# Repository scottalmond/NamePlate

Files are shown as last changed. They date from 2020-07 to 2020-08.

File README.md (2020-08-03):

# Name Plate Overview

Many cubicles are adorned with a standard aluminum name plate holding a piece of paper denoting the occupant's name.  This project presents an upgraded name tag that is backlit with LEDs.

This project was started as something simple to get active again after the COVID-19 lockdown.  Intent was to produce a visually engaging product with a price point at or below $25 in small production runs (10 units) to be in compliance with corporate gifting guidelines.

This unit employs nominally 100 WS2812B "NeoPixel" RGBW LEDs.  An ATtiny3216 was selected as a well supported processor (Arduino IDE) with a sizable flash memory (32kB).  To keep the design margin large, the SOIC package was selected.

The user can adjust the brightness of the unit through a potentiometer.  A Periphreal Touch Controller button allows quick user input while a hall effect sensor allows administrative functions.  A DIP switch allows for operation mode selection

# Assembled Unit

# Constituent Components

## Bill of Materials

## PCB

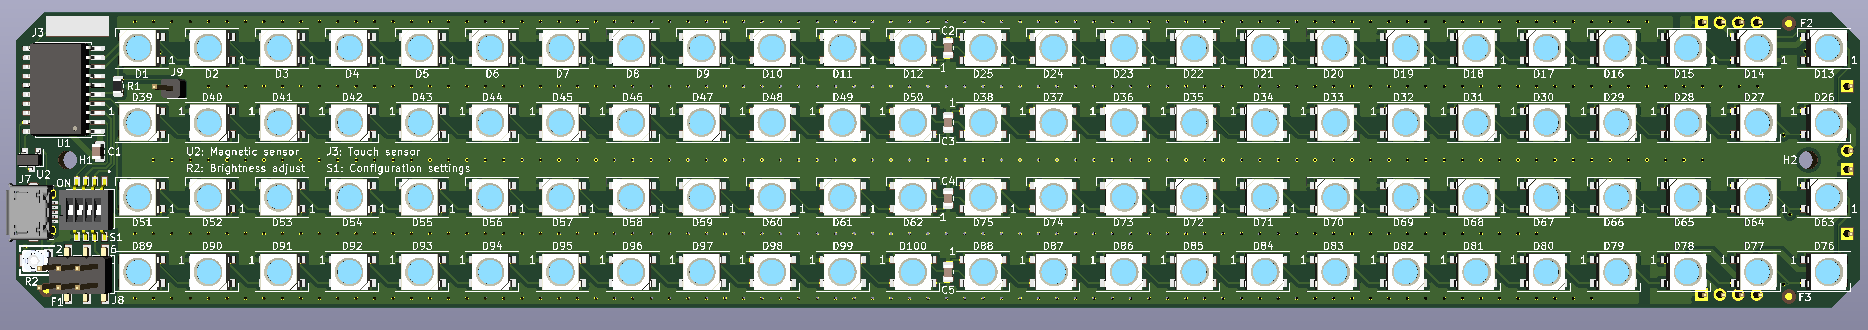
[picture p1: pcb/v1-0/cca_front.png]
CCA Front

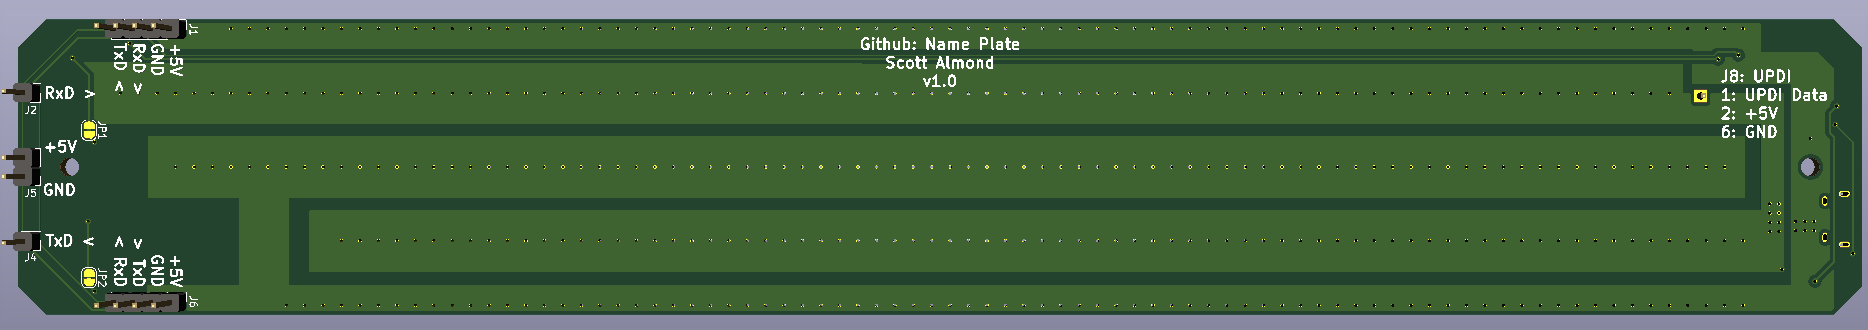
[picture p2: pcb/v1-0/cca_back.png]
CCA Back


## Case

## Display Mask

## Face Plate

## Programmer

Direct referenced from: http://www.technoblogy.com/show?2OCH

- Install ElTangas's jtag2updi on Arduino Uno, Duemilanova or equivalent ATmega328p.  -- Details for making UPDI programmer: https://github.com/SpenceKonde/megaTinyCore/blob/master/MakeUPDIProgrammer.md
-- Use pin PD6 for UPDI I/O
- Install Spence Konde's megaTinyCore in the Arduino IDE
-- Instructions: https://github.com/SpenceKonde/megaTinyCore/blob/master/Installation.md
-- add to additional board URLs: http://drazzy.com/package_drazzy.com_index.json
-- boards manager add: "megaTinyCore" v2.0.5
- Upload settings:
-- Processor: ATtiny3216
-- 4.2 V BOD
-- 16 MHz
-- Programmer: jtag2updi

J8:
Pin 1: UPDI
Pin 2: +5V
Pin 6: GND

## Processor

doc: http://ww1.microchip.com/downloads/en/DeviceDoc/ATtiny3216-17-DataSheet-DS40002205A.pdf

# Periphreals

## DC Power

Note that this unit can sink substancial current.  It is recommended to power the unit with a 5V USB adapter capable of sourcing 2 Amps or more.

## LEDs [PA7]

## Touch Button [PB0]

Touching and releasing the very upper-left corner of the device for nominally 0.5 seconds will register a tap.  The unit will transition  between display patterns.

## Hall effect sensor [PA3]

Place a fridge or hard drive magnet just above the USB port.  This will activate <TBD function - implemented as fallback if PTC was problematic>

## Brightness Potentiometer [PA2]

Uncover the circuit board by removing the two thumb screws on either side of the faceplate.  Rotate the Philips potentiometer at the bottom left of the unit CW (?) to increase brightness.

## DIP Switch Settings [PA6, PA5, PA4]

Position 1:
Set to "OFF" to allow the displayed pattern to automaically update daily.  Set to "ON" to hold the currrently displayed pattern indefinitely.

Position 2:
Set to "ON" to configure the unit for collaboration mode.  In this mode the unit will communicate with other circuit boards to coordinate the displayed pattern.  For single PCB operation, the normal operation mode is "OFF".

Position 3:
Set to "ON" to enable diagnostic mode to allow verification and troublshooting of the user interfaces and outputs.  "OFF" is normal device operation.

Position 4:
Set to "ON" to connect the ID pin of the microUSB port to to the UPDI pin on the micro controller.  This is used for programming of the device without removing the circuit board from the casing.  "OFF" is normal operation.

# Collaboration Mode [PxD: PB2, RxD: PB3]

Multiple PCBs can be linked together to produce a larger display.  
<TBR>

# TODO

Add area for writing in owner name on PCB, for tracking units through development (if code differs)
Add CC BY 4.0 license to schematic
add year produced to PCB
>>> allow for batteyr power and power switch
>>> consider accel and swinging unit to create persistence of vision text display
add schematic links to readme.md
get solder paste with thinner tip
*** move micro USB header - difficult to reach for rework with config switches behind it (layout design issue)
note: LED is N/C in layout - why not flagged in DRc...?
b/c omitted connection in schematic due to copy-paste omission...
***fix D60 connection to 5V in next rev (schematic DRC issue)
-- run DRC in schematic too...
note: screw reads ~4V on delivery
magnet stuck at 0.87V despite exposure to hard drive magnet...
tried with pullup, still rigid at 0.87V
part is hot to the touch
note, the schematic part is AH1806 (hall switch) which has different pinout
- used this footprint because no footprint was supplied by vendor
*** next rev to swap pins 2 and 3 (schematic footprint issue)
consider testability point for EVERY IO
in user guide, include diagrams of expected UI screen output, ref 11.7V battery charger manual
include build number in start up script
compare findings on this CCA vs pendant which had button rotate 90 degrees (schematic footprint issue) and traces too close to holes (layout issue)
consider swapping hall effect sensor and brightness - allow greater accessibility to magnetic input
note:0.37" from LED-surface to top of programming header [note: 0.38" per data sheet, erxcluding solder]
contiguous undervolt - dim screen brighntess (LiPo response to dropping voltage)
min stackup (NO 1/16" acry): pcb 1.6 mm/0.063", 100 mil UPDI: 0.37", 0.125" acrylic face, 0.05" margin: 0.608"
max stackup (NO 1/16" acry): [5 turns 4-40 is 0.1250"] [50 mil backing], 200 mil standoff, 0.608" from above: 0.808"
min w/ 1/16 acry: 0.63+ above = 0.671"
max w/ 1/16 acry: 0.63+ above = 0.871"
note: thumb screw head 11/64" thick BEYOND base length above
0.75" is max length fully threaded.  next step up is 1"
note: head diameter on thumb screw is 5/16"
.75-1/8"+.05 back = 
box height at 0.8".  Add 1/16" when fabricating with acrylic
>>> enlarge PCB holes to be close fit.  Currently too small
allow for flipping vertically - flip flag, matrix rtain, etc
>>> consider moving silk screen contact info to behind a hole in the back of the unit
v1-0 --> v1-1 case:
50 mil WAS --> 100 mil IS margin inside pcb-to-case
50 mil WAS --> 150 mil IS wall thickness
WAS circle vent holes --> IS diamond vent holes --> will turn off supports
WAS 4x PCB holders, IS 2x PCB holders in the center
WAS NO chamfer inside unit --> IS chamfer around inner edge to provide wall support
WAS 4x faceplate holders --> IS NO facaeplate holders
WAS NO USB port --> IS USB PORT --> need dimensions of usb plug, and concern with unsupported 3d print
micro usb header metal = 0.07", 0.2" from opposing side of usb to verrtical case edge, 0.31" total
0.27" wide, 0.35" from opposing edge to case, 0.43" total
kicad center hole at 3.8" Y, 4.083" for microUSB port center
microUSB center 1.2 mm above surface of PCB
consider first boot (all 1's in EEPROM) to debug chaper.  First user input to change EEPROM exits hidden chapter
*** consider screw slots due to 3d print contraction
current draw?
leakage through usb port?
*** add lip to top edge to hide cut paper
consider standoffs (3d print?)
wasn't thinking about plastic contraction between ~10" separated holes
didn't think about light leakage through walls of solid plastic
note: the link from this pcb to others on the top/bottom has led pads very clodse to the power/ground rails
note: grips to hold pcb in place are non-effective (pcb too thin?)
consider pcb design features that allow for 2x rows of LEDs, NOT 4
didn't realize how short the final letts would be
debug screen: voltage, build #
1.8A at full brightness in full-screen mode (green colors)

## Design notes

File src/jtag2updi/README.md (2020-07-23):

# jtag2updi

This fork of the repo has been stripped down and modified so that folders don't need to be renamed in order to compile with the Arduino IDE. 
## New Features
This has also has the following additions:
* Support for DA-series and upcoming DB-series parts; correct mode for reading and writing is deduced by reading the SIB
* Timeout function - a lack of messages from host for 250ms or the target failing to send an expected response for 100ms will result in a timeout. Timeouts from target are reported to host. Timeouts waiting for host will lead to it attempting to reset a failed status message (on the grounds that "maybe it didn't get through". Four consecutive timeouts waiting for host will cause it to reset to it's initial state and await a new attempt at communication from the host. 
* Improve write speed by disabling the response signature during burst writes (NO_ACK_WRITE).
* Add debug channel via SPI or second USART to provide rich debugging output.
* Add support for running on addittional processors: 40/44 pin ATmega parts (ones supported by MightyCore), 64/100-pin ATmega parts (ones supported by MegaCore), 28/32-pin ATmega parts (ones supported by MiniCore), and megaAVR 0-series parts (supported by MegaCoreX). The tinyAVR 0-series and 1-series parts (supported by megaTinyCore) are also supported.

## Known issues
There are the following known issues:
* Timeout system breaks compatibility with terminal mode (-t option), by definition, as a user in terminal mode will inevitably take longer than it is configured to wait. This will be corrected via a planned SUPPORT_TERMINAL_MODE option for those small number of users who use terminal mode.
* Does not work correctly on LGT-based clones
* has_pdi does not work correctly (waiting to hear back whether it is broken for all parts or just DA-series parts)
* Does not run on DA-series parts - This will be corrected by addition of a few more defines, should be easy
* Does not support targets operating at a low voltage - this could be solved by using an analog comparator for receiving, and using pin in "open drain" mode for transmitting, but I doubt I'll ever bother to implement this.

# Original Readme
This is a firmware, that when uploaded on an atmega328p, or a similar AVR MCU, enables it to interface with avrdude using the jtagice Mk2 protocol via a serial link. In particular, you can use an Arduino to host this firmware.
It provides a bridge to program the new attiny817 family of MCUs, that use the UPDI interface:

avrdude -> HW Serial interface -> Programmer MCU (e.g. Mega328P) -> SW Serial on PD6 -> Target MCU (e.g. tiny817)

Currently, I have not tested this software with a level shifter, however, since the UPDI pin is high voltage tolerant, it's ok to have V_prog > V_target, but not the reverse.

Notice, however, that the logic levels need to be compatible for successful programming: V_target cannot be lower than about 60% of V_prog (60% will likelly work, 70% is guaranteed to work). Therefore, it will not be possible to program a 2.5V target with a 5.0V programmer, because communication errors will surely occur (but no electrical damage), but if V_target is 3.3V (66% of 5.0V) chances are good.

<pre>
                                            V_prog                 V_target
                                              +-+                     +-+
                                               |                       |
 +----------+          +---------------------+ |                       | +--------------------+
 | PC       |          | Programmer          +-+                       +-+  Target            |
 | avrdude  |          |                     |      +----------+         |                    |
 |       TX +----------+ RX              PD6 +------+   4k7    +---------+ UPDI               |
 |          |          |                     |      +----------+         |                    |
 |       RX +----------+ TX                  |                           |                    |
 |          |          |                     |                           |                    |
 |          |          |                     |                           |                    |
 |          |          |                     +--+                     +--+                    |
 +----------+          +---------------------+  |                     |  +--------------------+
             JTAGICE MkII                      +-+     UPDI          +-+
             Protocol                          GND     Protocol      GND

</pre>
Drawing adapted from: https://github.com/mraardvark/pyupdi

If you use an Arduino as host for this program, be sure that, after burning the software, you disable its auto-reset feature, using one of the techniques described here:
https://playground.arduino.cc/Main/DisablingAutoResetOnSerialConnection

Alternatively, you can use an Arduino without integrated USB/serial adapter, like the pro-mini; in that case, just disconecting the DTR wire will disable the auto-reset. Just remember the UPDI chip must be connected to the same supply voltage as the Arduino's MCU!

## Building with Arduino IDE

The program can be built as if it was an Arduino sketch. 

Open jtag2updi.ino in the jtag2updi folder, and upload to your microcontroller. 

The Arduino IDE will automatically set the correct MCU model and F_CPU, but if you want to change the speed of the UPDI link, you will have to edit UPDI_BAUD directly in the source code.

## Using with avrdude

**If using megaTinyCore, you can ignore all this stuff**

You will find a modified avrdude.conf file in the base folder. This is based on the current avrdude.conf file from:
http://svn.savannah.gnu.org/viewvc/*checkout*/avrdude/trunk/avrdude/avrdude.conf.in?revision=1422

It has been modified to work with avrdude 6.3, by removing (actually, commenting out) some incompatible stuff, and adding the "jtag2updi" programmer type.

The definitions for UPDI chips were slightly modified so that avrdude thinks they use the PDI programming interface instead of UPDI (i.e., avrdude thinks they are some kind of XMegas).

This allows the jtagice mk2 protocol to be used for programming UPDI chips, since this protocol predates UPDI and is not formally compatible with it. Originally, I had planed to use the STK500v2 protocol, and emulate the ISP interface, and I actually wrote an ISP version of the programmer software.

However, this would require entirely new definitions for the UPDI chips inside the avrdude.conf file, while using jtagice2 requires only very slight changes to the definions provided by Atmel (now Microchip).

Jtagice mk2 is the most advanced of Atmel's programming protocols that still supports a UART serial connection instead of USB, making it easily compatible with any Arduino you choose to host this software, and any OS you run avrdude on.

It's major limitation is speed; it can't go over 115200 Baud, because the protocol lacks definitions for higher speeds. It's actually inferior to the STK500v2 protocol in this respect, this older standard can run at any speed avrdude instructs it to.

Fortunately, the current UPDI chips do not have very large flash memories, so I think this isn't a major issue.

<b>Example command line (windows):</b>
<pre>
avrdude -c jtag2updi -P com7 -p t1614
</pre>

If all the connections are correct and the target is indeed an *unlocked* tiny1614, the output will be:
<pre>
avrdude: AVR device initialized and ready to accept instructions

Reading | ################################################## | 100% 0.03s

avrdude: Device signature = 0x1e9422 (probably t1614)

avrdude done.  Thank you.
</pre>

If the chip is locked, the output will be:
<pre>
avrdude: jtagmkII_reset(): bad response to reset command: RSP_ILLEGAL_MCU_STATE
avrdude: initialization failed, rc=-1
         Double check connections and try again, or use -F to override
         this check.

avrdude: jtagmkII_close(): bad response to sign-off command: RSP_ILLEGAL_MCU_STATE

avrdude done.  Thank you.
</pre>

To unlock the chip, you need to erase it. Currently, the "-e" option is not working with jtag2updi, let's call it a known bug, so you need to enter interactive mode, using "-t", and "-F" to override the error:
<pre>
avrdude -c jtag2updi -P com7 -p t1614 -U flash -t -F
</pre>

You will enter the avrdude prompt:
<pre>
avrdude: jtagmkII_reset(): bad response to reset command: RSP_ILLEGAL_MCU_STATE
avrdude: initialization failed, rc=-1
avrdude: AVR device initialized and ready to accept instructions
avrdude: Device signature = 0xffff00
avrdude: Expected signature for ATtiny1614 is 1E 94 22
avrdude: NOTE: Programmer supports page erase for Xmega devices.
         Each page will be erased before programming it, but no chip erase is performed.
         To disable page erases, specify the -D option; for a chip-erase, use the -e option.
avrdude>
</pre>

Enter "erase" then "quit" and the chip will be unlocked (and erased).
<pre>
avrdude> erase
>>> erase
avrdude: erasing chip
avrdude> quit
>>> quit

avrdude done.  Thank you.
</pre>

## Troubleshooting

If you have triple-checked all the connections but still getting errors, the problem might be the speed of the serial links. I have set the jtag2updi entry on the avrdude configuration file to run at 115200 baud by default. This baud rate can cause errors, for example, if your MCU is running at 8MHz.

This can be changed with the avrdude "-b" option. Valid baud rates are 2400, 4800, 9600, 14400, 19200, 38400, 57600 and 115200. You can make the setting permanent by editing the jtag2updi entry on "avrdude.conf".

If the trouble is on the UPDI link, a slower speed can be selected by changing UPDI_BAUD and recompiling.

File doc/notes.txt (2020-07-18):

1,3
11,4.6

1.25,3.25
10.75,4.35

1.262,3.262
10.738,4.338

1.012,3.012
10.988,4.588

11 - .2 -.015

24 10.785
0 

10.818 + .012
10.83

0.17" edge
3.182

4.6-.17-.012
11-.17-.012

.14 

24 10.785
0 1.65

*24 10.804
delta 0.38
*0 1.684

1.684+C*0.38
3.2, 3.6, 4.0, 4.4 --> 0.403
3.1955,3.5985,4.0015,4.4045
rows 0 and 2 rotated 180

0.38 per LED hori

-- case

PCB: 1.6 x 10"
outline +- 0.15 mm --> 0.006"

1.6+.006+.006 = 1.612
round up to 50 mil
1.65 inner
1.7 outer

same horizontally
10.05 inner
10.1 outer

.15 cut on PCB

10.72 hole
1.28 hole
9.44" apart

40 threads per inch on 4-40
5 threads engaged minimum
0.125" plastic

also allow 50 mil error on height

4-40 hole size
https://learn.sparkfun.com/tutorials/getting-started-with-3d-printing-using-tinkercad/taking-measurements

consider heat set inserts for repeated insertion/extraction of thumb screws

screw into cubicle wall with something on the order of #2 gauge 1/4"?
https://titleplates.com/resources/attaching-nameplates.html

consider for how to get cabling out of rear

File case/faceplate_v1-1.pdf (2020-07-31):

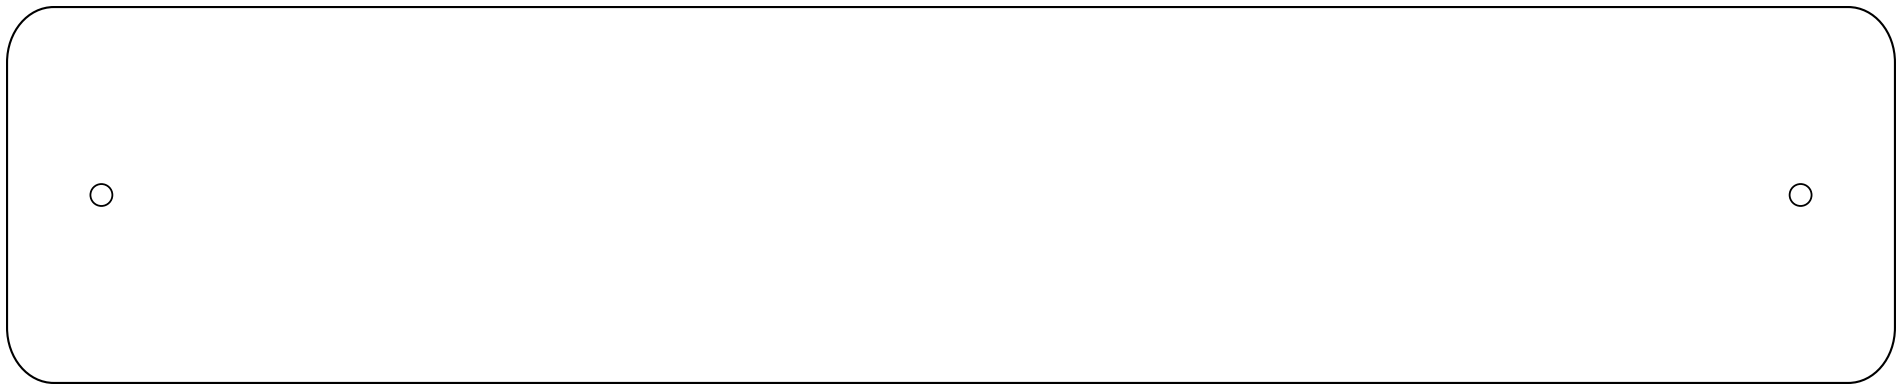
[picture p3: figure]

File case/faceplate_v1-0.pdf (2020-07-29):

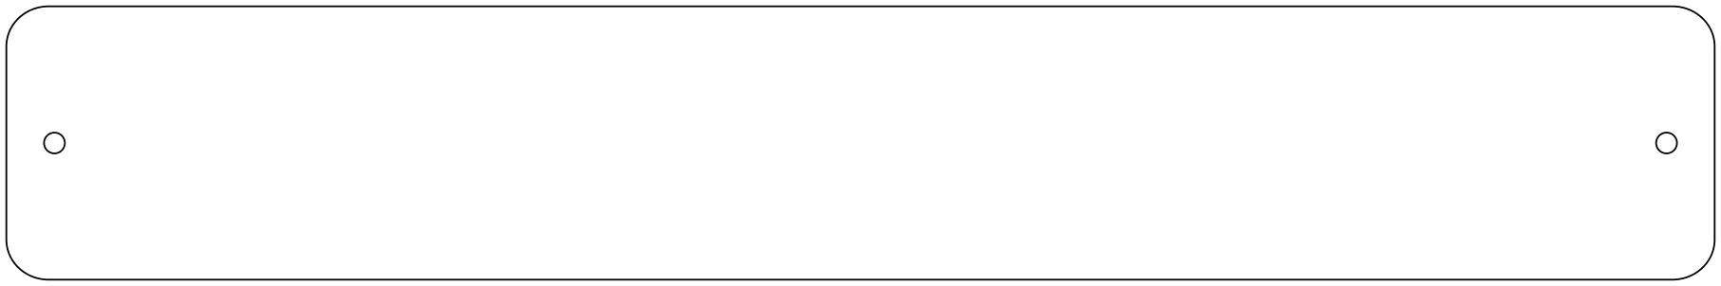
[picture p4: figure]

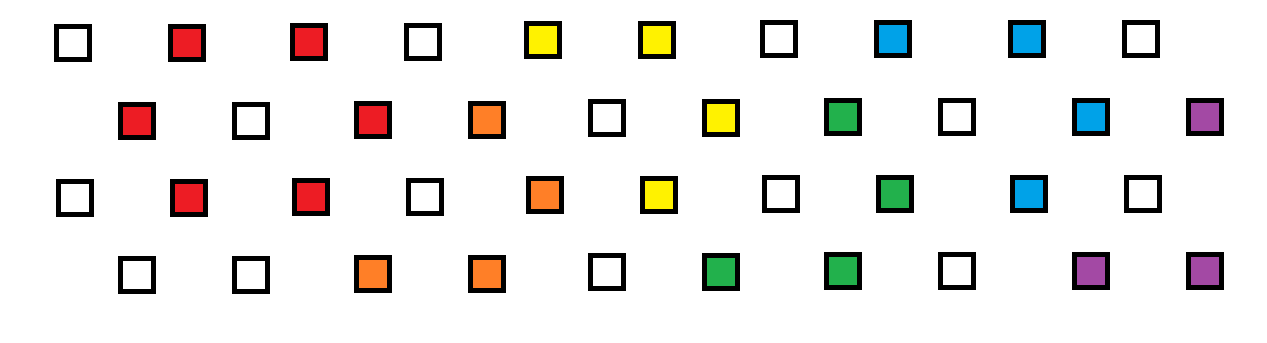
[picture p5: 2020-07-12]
doc/circle_loops_animation_concept.png

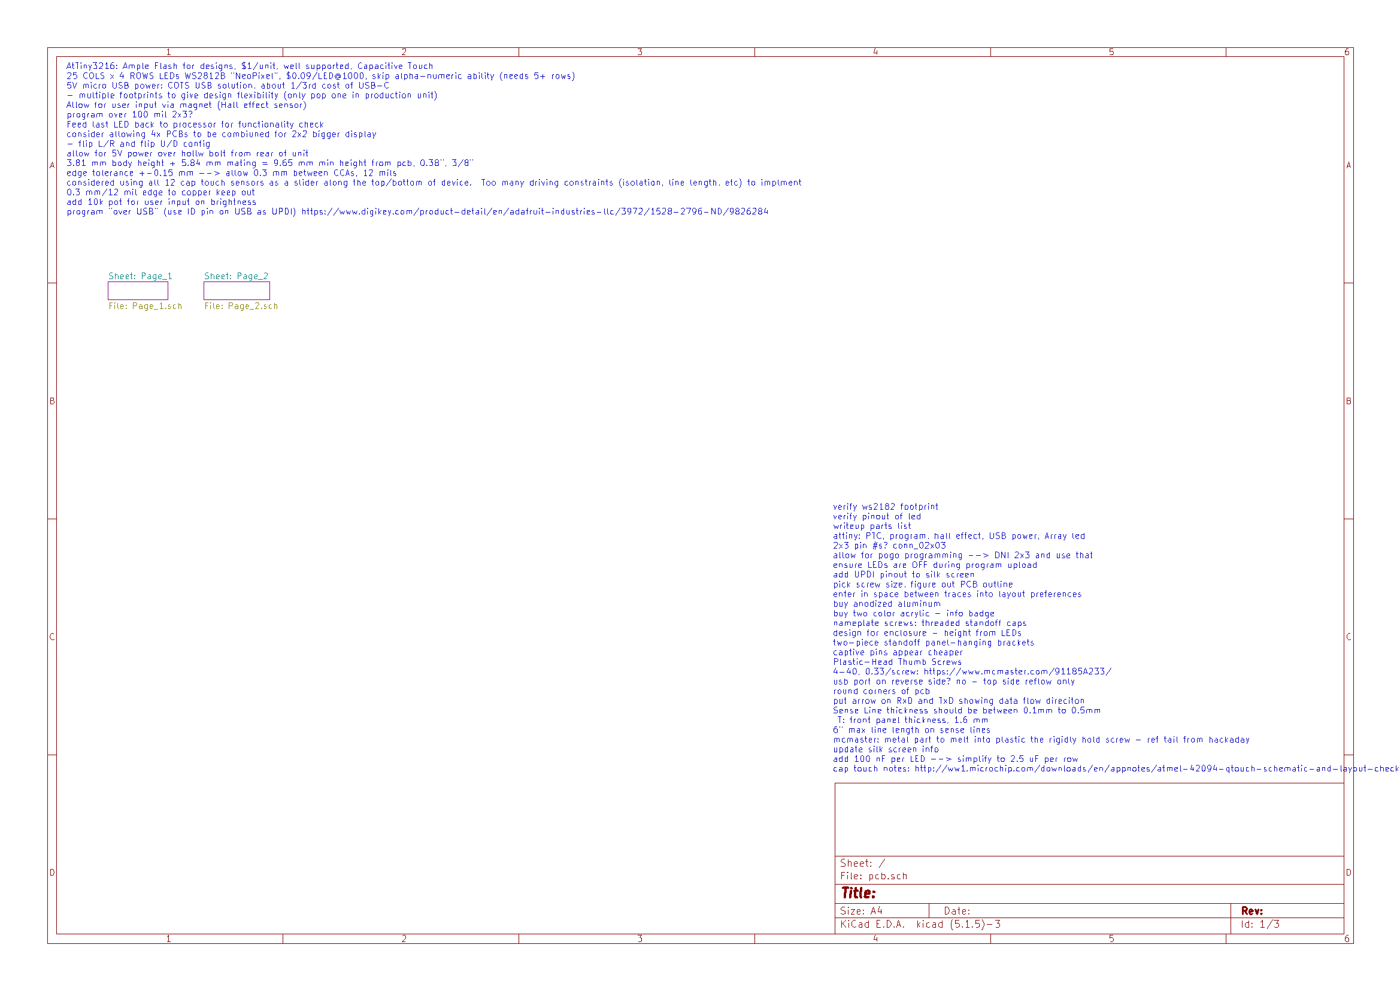
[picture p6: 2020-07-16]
pcb/v1-0/schematic_notes.png

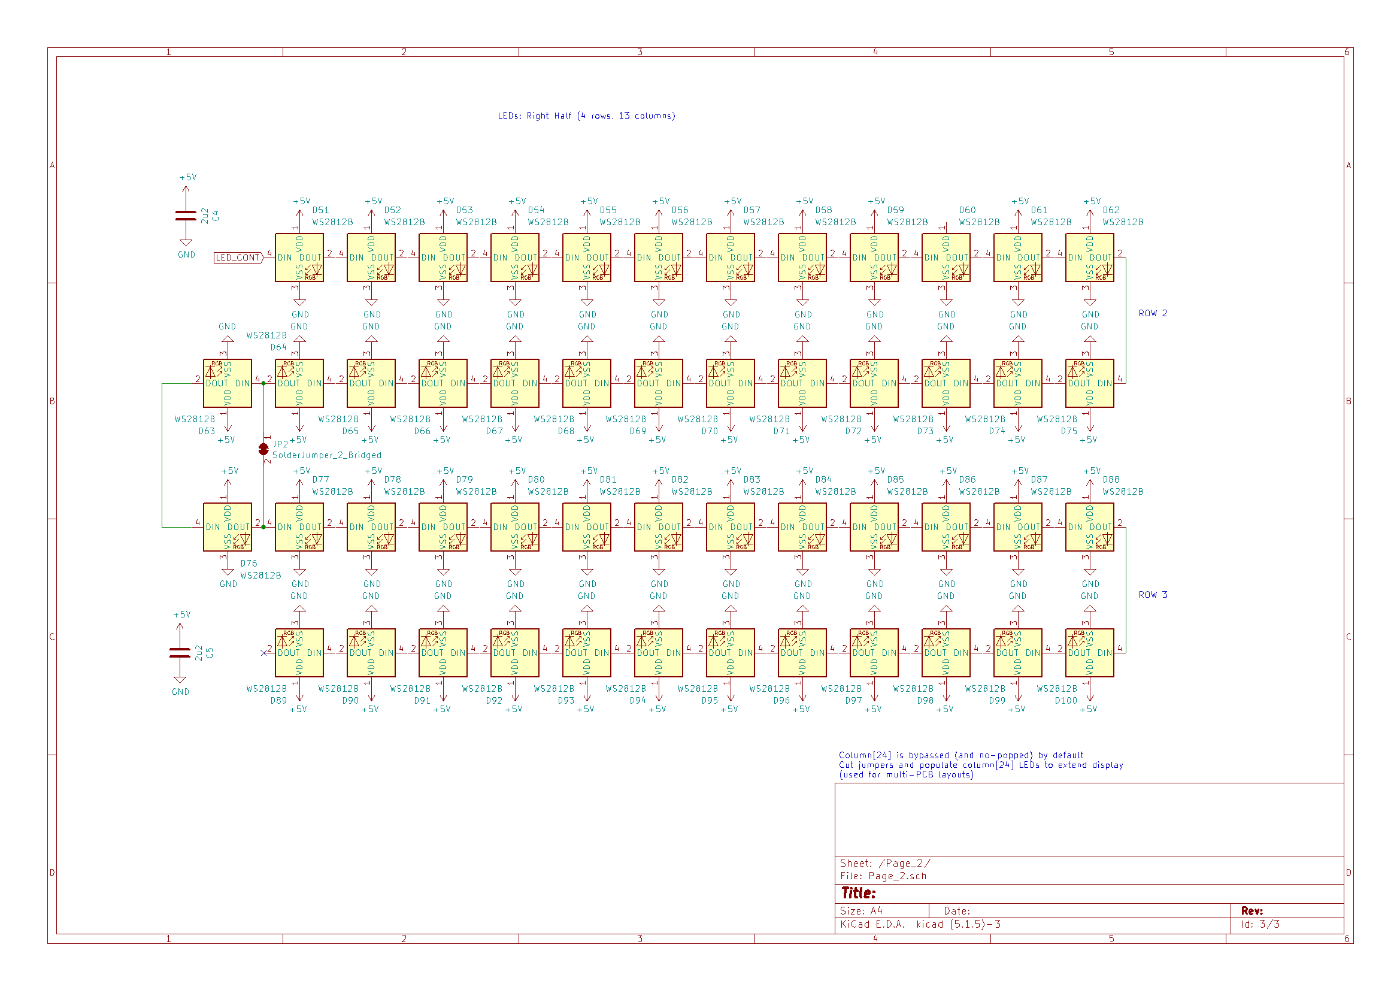
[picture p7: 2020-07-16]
pcb/v1-0/schematic_page2.png

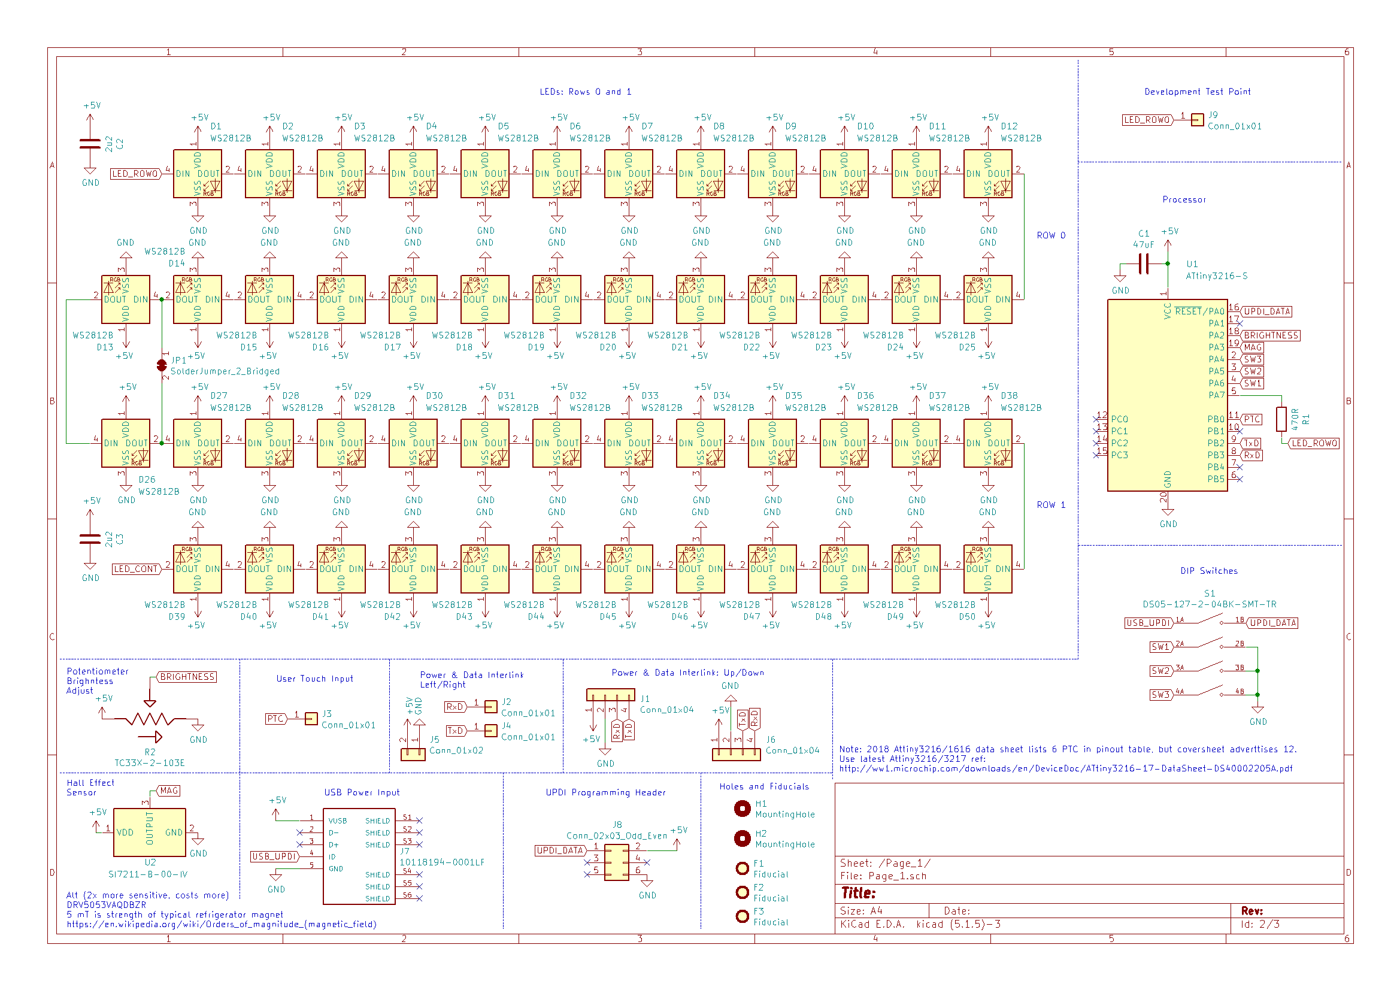
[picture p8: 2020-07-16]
pcb/v1-0/schematic_page1.png

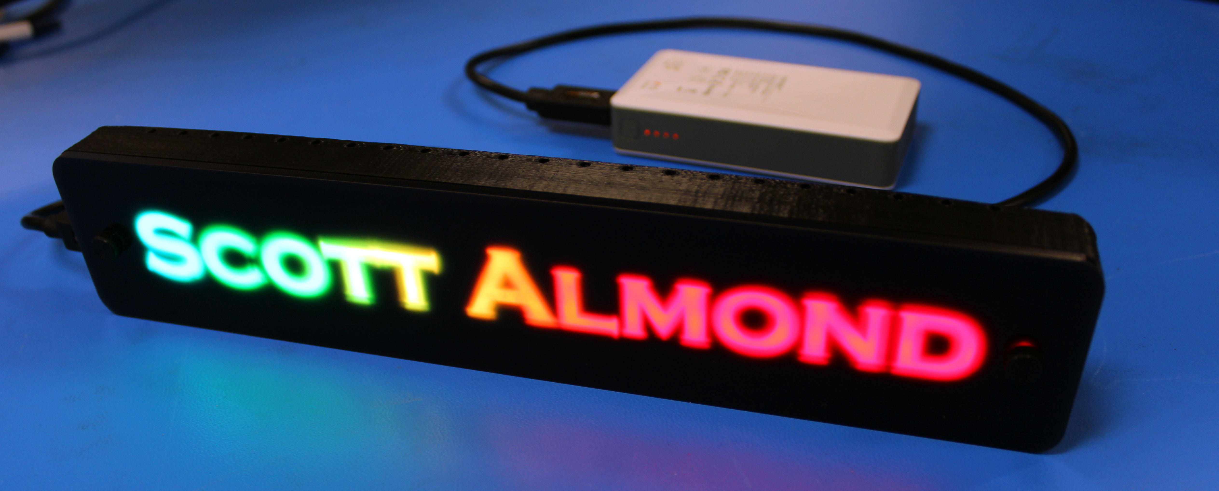
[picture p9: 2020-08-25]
doc/img/IMG_5587_cropped.JPG

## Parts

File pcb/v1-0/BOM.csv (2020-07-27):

Footprint | Part Number | Value | Description | Qty/assembly | Unit Price (@10 assemblies) | Extended Price per Unit | Link
C1 | CC0805MKX5R5BB476 | 47 uF | 0805 Capacitor, >5V | 1 | 0.341 | 0.341 | https://www.digikey.com/product-detail/en/yageo/CC0805MKX5R5BB476/311-1897-1-ND/5195799
J7 | 10118194-0001LF |  | micro USB Header | 1 | 0.405 | 0.405 | https://www.digikey.com/product-detail/en/amphenol-icc-fci/10118194-0001LF/609-4618-1-ND/2785382
J8 | 54202-G08-03 |  | 2x3 100 mil vertical SMT | 1 | 0.352 | 0.352 | https://www.digikey.com/product-detail/en/amphenol-icc-fci/54202-G08-03/609-5602-ND/1488240
R1 | RMCF0805JT470R | 470R | 0805 resistor | 1 | 0.019 | 0.019 | https://www.digikey.com/product-detail/en/RMCF0805JT470R/RMCF0805JT470RCT-ND/1942551/
R2 | TC33X-2-103E | 10k | SMT Potentiometer | 1 | 0.277 | 0.277 | https://www.digikey.com/product-detail/en/bourns-inc/TC33X-2-103E/TC33X-103ECT-ND/612911
S1 | DS05-127-2-04BK-SMT-TR | 4x | SMT DIP Switches 50 mil | 1 | 1.26 | 1.26 | https://www.digikey.com/product-detail/en/cui-devices/DS05-127-2-04BK-SMT-TR/2223-DS05-127-2-04BK-SMT-CT-ND/11312443
U1 | ATtiny3216 |  | SMT ATtiny3216 | 1 | 1 | 1 | https://www.digikey.com/product-detail/en/microchip-technology/ATTINY3216-SNR/ATTINY3216-SNRCT-ND/9477803
U2 | SI7211-B-00-IV | 20 mT | Hall Effect Sensor | 1 | 0.68 | 0.68 | https://www.digikey.com/product-detail/en/silicon-labs/SI7211-B-00-IV/336-4057-ND/7323036
C2-C5 | CL21B225KPFNNNE | 2.2 uF | 0805 Capacitor, >5V | 4 | 0.0498 | 0.1992 | https://www.digikey.com/product-detail/en/CL21B225KPFNNNE/1276-1188-1-ND/3889274/?itemSeq=332167250
STE | 3972 |  | microUSB breakout | 1 | 6.5 |  | https://www.digikey.com/product-detail/en/3972/1528-2796-ND/9826284
STE | SMD291AX? |  | Solder Paste | 1 | 14.99 |  | https://www.digikey.com/product-detail/en/SMD291AX/SMD291AX-ND/1160002/?itemSeq=329328494
 |  |  | Shipping |  | 4.99 | 0.499
 |  |  | Tariff |  | 2.36 | 0.236
 |  |  | Tax |  | 7.32 | 0.732
 |  |  | Neutral White RGBW | 100 | 0.08784 | 8.784 | https://www.aliexpress.com/item/32641663497.html?spm=a2g0s.9042311.0.0.43174c4dztINSE
 |  |  | Shipping, taxes |  |  | 0.854
 |  | unit thickness? | Knob | 2 | 9.84 | 0.7872 | https://www.mcmaster.com/91185A249-91185A223/
 |  |  | Shipping, taxes |  |  | applicagble tax and shipping will be added?
 |  | 11x2" | Frosted Acrylic | 1 | 1.314 | 1.314 | https://www.tapplastics.com/product/plastics/cut_to_size_plastic/black_led_sheet/668
 |  |  | Shipping |  | 10.4 | 1.04 | 11 x 20"
 |  |  | Tax |  | 3.51 | 0.351
 |  | 1.6x10" | PCB |  | 16 | 1.6 | https://www.allpcb.com/online_pcb_quote.html?hidLength=10&hidWidth=10&hidNum=10&hidLayers=2&BoardThickness=1.6
 |  |  | Shipping, taxes |  | 27.56 | 2.756
 |  |  | Construction paper |  | 6.29 | 0.629 | https://www.cvs.com/shop/content/construction-paper
 |  |  | tax |  | 0.59755 | 0.059755
 |  | 12.410 * 4.062" | OshStencil 3 mil Polyimide, 1.25" boarder |  | 22.4 | 2.24
 |  |  | tax |  | 2.95 | 0.295
 |  |  | shipping
 |  |  | Sum |  |  | 26.710155

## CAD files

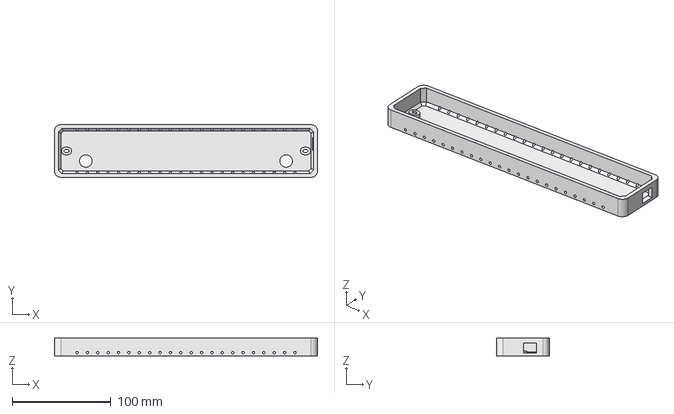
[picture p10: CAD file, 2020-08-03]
case/case_v1-2.FCStd
266.7 x 53.3 x 17.8 mm

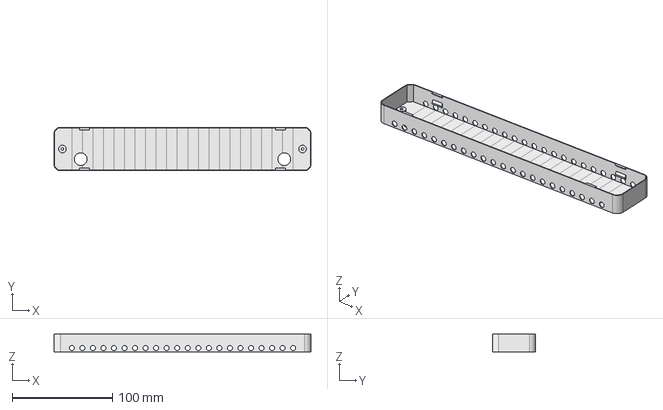
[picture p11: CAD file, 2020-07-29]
case/case_v1-0.step
256.5 x 43.2 x 17.8 mm

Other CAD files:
case/case_v1-3.FCStd
case/case_v1-1.FCStd
case/case_v1-0.FCStd
case/case_v1-0.obj
case/case_v1-0.stl
case/case_v1-1.obj
case/case_v1-1.stl
case/case_v1-2.obj
case/case_v1-2.stl
case/case_v1-3.obj
case/case_v1-3.stl

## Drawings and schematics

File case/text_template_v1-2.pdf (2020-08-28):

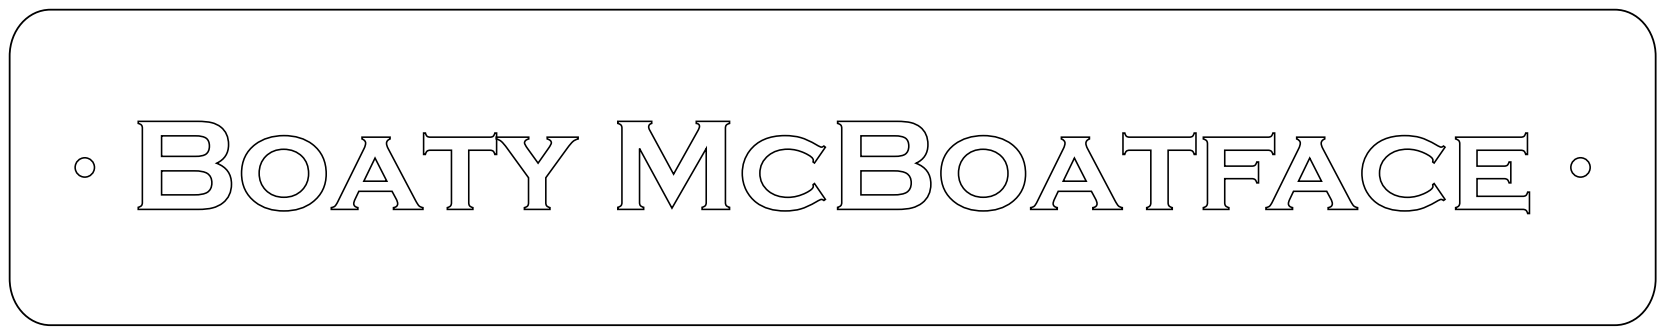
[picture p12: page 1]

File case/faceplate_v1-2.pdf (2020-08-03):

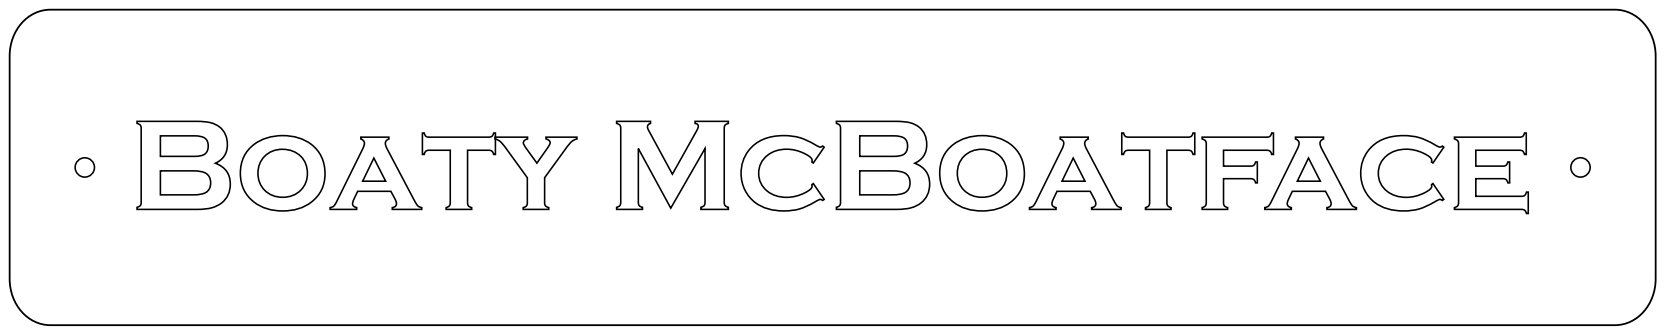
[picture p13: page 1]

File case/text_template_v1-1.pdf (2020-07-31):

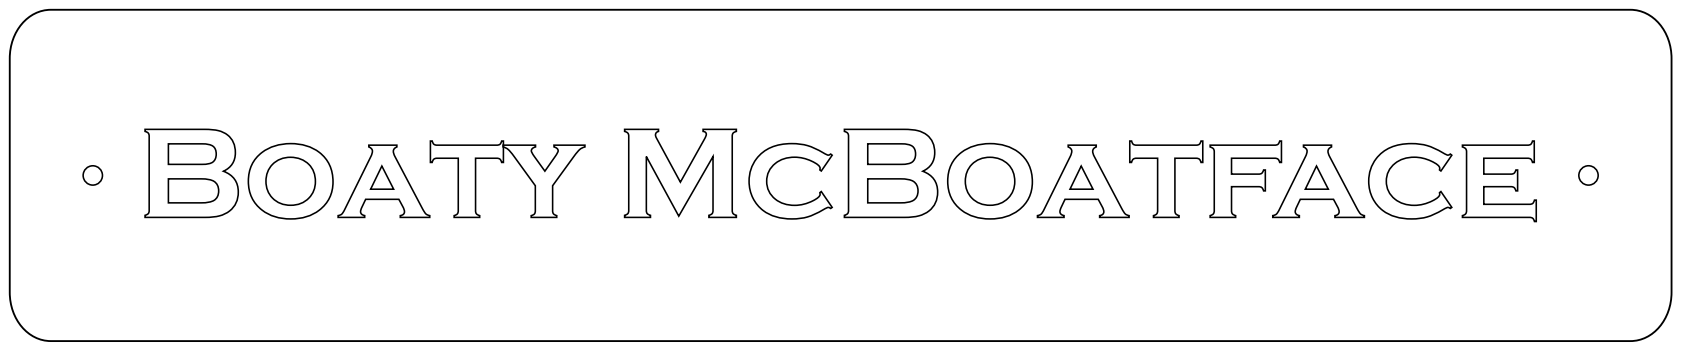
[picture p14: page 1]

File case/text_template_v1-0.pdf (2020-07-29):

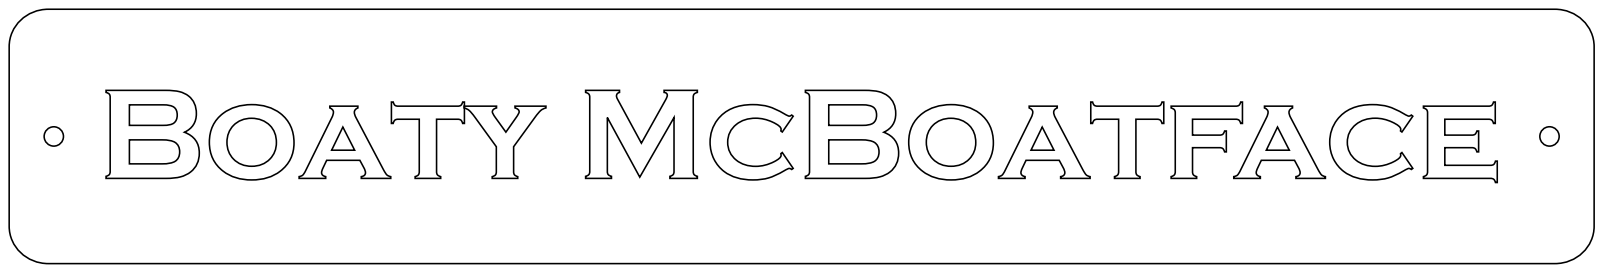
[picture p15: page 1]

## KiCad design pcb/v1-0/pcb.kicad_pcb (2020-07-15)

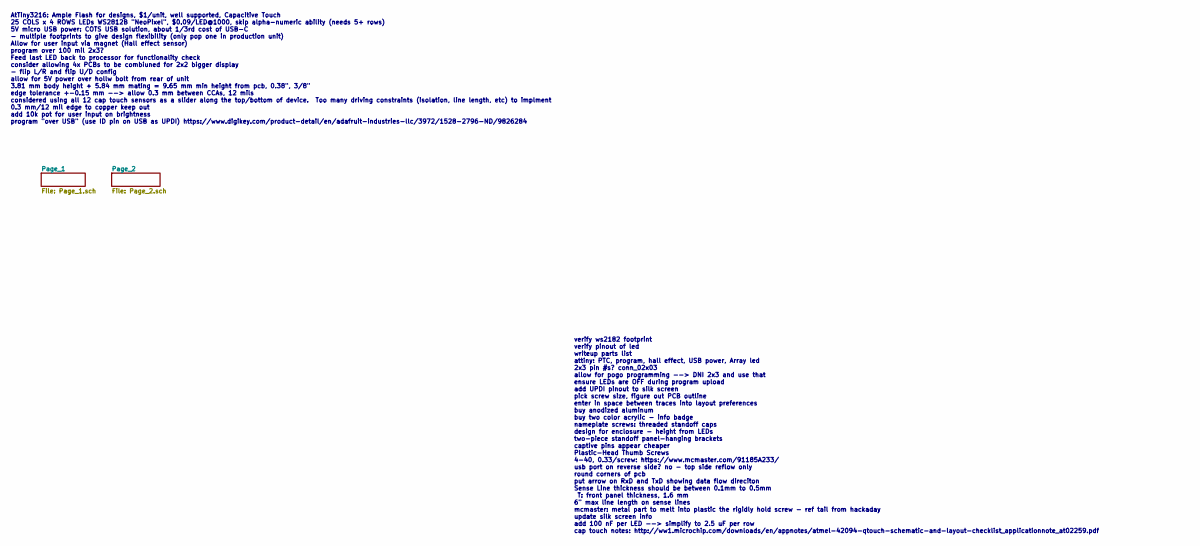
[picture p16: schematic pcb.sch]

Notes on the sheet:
verify ws2182 footprint verify pinout of led writeup parts list attiny: PTC, program, hall effect, USB power, Array led 2x3 pin #s? conn_02x03 allow for pogo programming --> DNI 2x3 and use that ensure LEDs are OFF during program upload add UPDI pinout to silk screen pick screw size, figure out PCB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
AtTiny3216: Ample Flash for designs, $1/unit, well supported, Capacitive Touch 25 COLS x 4 ROWS LEDs WS2812B "NeoPixel", $0.09/LED@1000, skip alpha-numeric ability (needs 5+ rows) 5V micro USB power: COTS USB solution, about 1/3rd cost of USB-C - multiple footprints to give design flexibility (only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

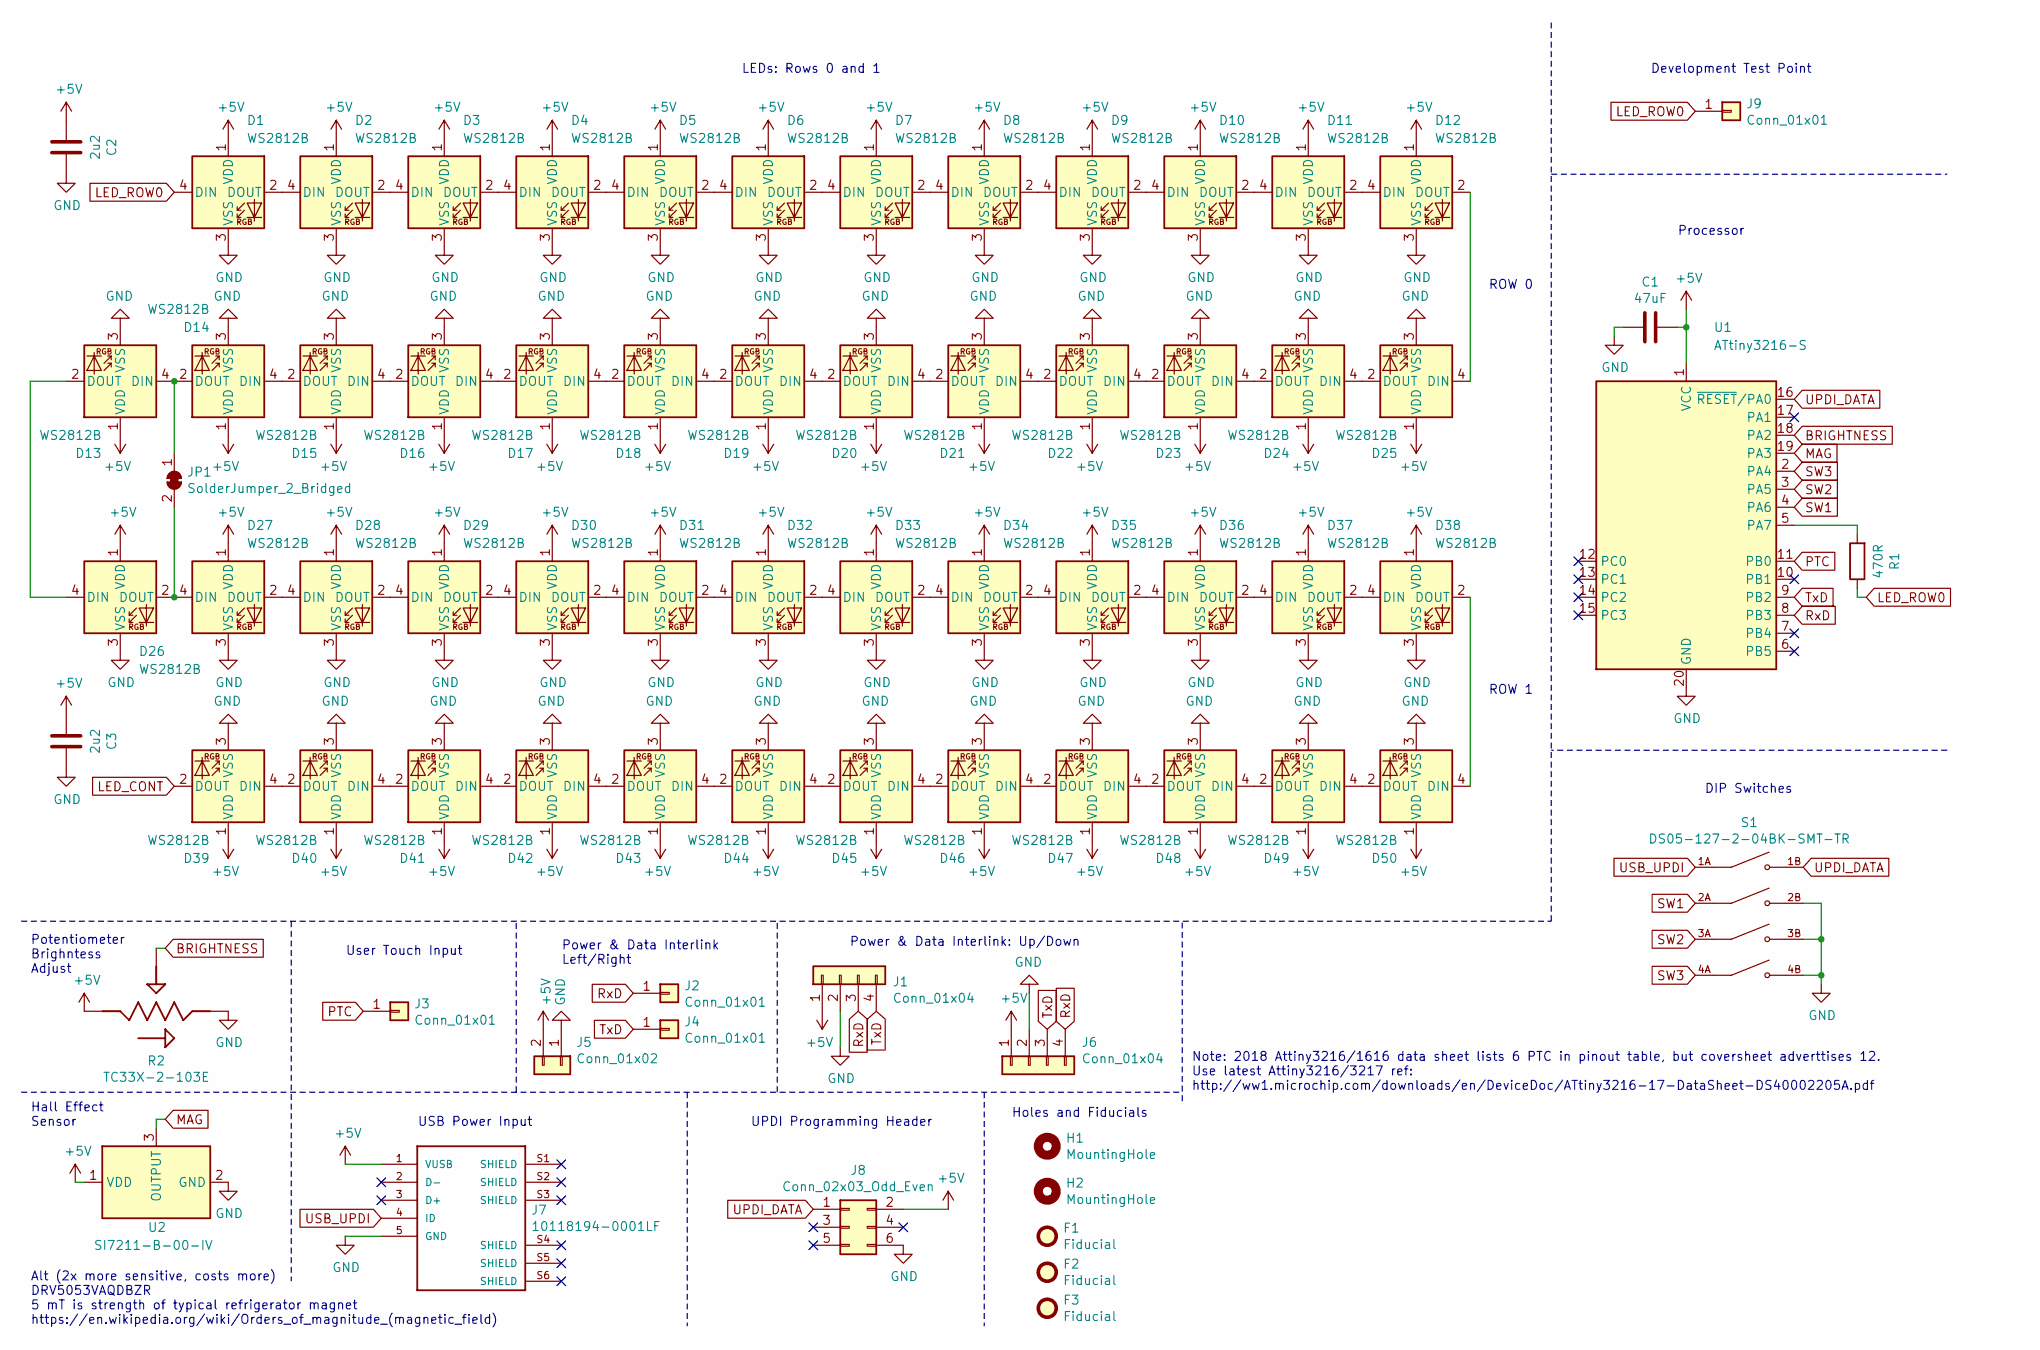
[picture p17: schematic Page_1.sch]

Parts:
C1: 47uF; C_0805_2012Metric
C2, C3: 2u2; C_0805_2012Metric
D1, D2, D3, D4, D5, D6, D7, D8, D9, D10, D11, D12, D13, D14, D15, D16, D17, D18, D19, D20, D21, D22, D23, D24, D25, D26, D27, D28, D29, D30, D31, D32, D33, D34, D35, D36, D37, D38, D39, D40, D41, D42, D43, D44, D45, D46, D47, D48, D49, D50: WS2812B; LED_WS2812B_PLCC4_5.0x5.0mm_P3.2mm
F1, F2, F3: Fiducial; Fiducial_1mm_Mask2mm
H1, H2: MountingHole; MountingHole_2.5mm
J1, J6: Conn_01x04; PinHeader_1x04_P2.54mm_Vertical
J2, J4, J9: Conn_01x01; PinHeader_1x01_P2.54mm_Vertical
J3: Conn_01x01; cap_touch
J5: Conn_01x02; PinHeader_1x02_P2.54mm_Vertical
J7: 10118194-0001LF; AMPHENOL_10118194-0001LF
J8: Conn_02x03_Odd_Even; PinHeader_2x03_P2.54mm_Vertical_SMD
JP1: SolderJumper_2_Bridged; SolderJumper-2_P1.3mm_Bridged_RoundedPad1.0x1.5mm
R1: 470R; R_0805_2012Metric
R2: TC33X-2-103E; 35WR
S1: DS05-127-2-04BK-SMT-TR; SW_DS05-127-2-04BK-SMT-TR
U1: ATtiny3216-S; SOIC-20W_7.5x12.8mm_P1.27mm
U2: SI7211-B-00-IV; SC-59

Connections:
+5V: C1.1, C2.2, C3.2, D1.1 (VDD), D2.1 (VDD), D3.1 (VDD), D4.1 (VDD), D5.1 (VDD), D6.1 (VDD), D7.1 (VDD), D8.1 (VDD), D9.1 (VDD), D10.1 (VDD), D11.1 (VDD), D12.1 (VDD), D13.1 (VDD), D14.1 (VDD), D15.1 (VDD), D16.1 (VDD), D17.1 (VDD), D18.1 (VDD), D19.1 (VDD), D20.1 (VDD), D21.1 (VDD), D22.1 (VDD), D23.1 (VDD), D24.1 (VDD), D25.1 (VDD), D26.1 (VDD), D27.1 (VDD), D28.1 (VDD), D29.1 (VDD), D30.1 (VDD), D31.1 (VDD), D32.1 (VDD), D33.1 (VDD), D34.1 (VDD), D35.1 (VDD), D36.1 (VDD), D37.1 (VDD), D38.1 (VDD), D39.1 (VDD), D40.1 (VDD), D41.1 (VDD), D42.1 (VDD), D43.1 (VDD), D44.1 (VDD), D45.1 (VDD), D46.1 (VDD), D47.1 (VDD), D48.1 (VDD), D49.1 (VDD), D50.1 (VDD), J1.1, J5.2, J6.1, J7.1 (VUSB), J8.2, R2.1, U1.1 (VCC), U2.1 (VDD); also elsewhere on the board
BRIGHTNESS: R2.2, U1.18 (PA2)
GND: C1.2, C2.1, C3.1, D1.3 (VSS), D2.3 (VSS), D3.3 (VSS), D4.3 (VSS), D5.3 (VSS), D6.3 (VSS), D7.3 (VSS), D8.3 (VSS), D9.3 (VSS), D10.3 (VSS), D11.3 (VSS), D12.3 (VSS), D13.3 (VSS), D14.3 (VSS), D15.3 (VSS), D16.3 (VSS), D17.3 (VSS), D18.3 (VSS), D19.3 (VSS), D20.3 (VSS), D21.3 (VSS), D22.3 (VSS), D23.3 (VSS), D24.3 (VSS), D25.3 (VSS), D26.3 (VSS), D27.3 (VSS), D28.3 (VSS), D29.3 (VSS), D30.3 (VSS), D31.3 (VSS), D32.3 (VSS), D33.3 (VSS), D34.3 (VSS), D35.3 (VSS), D36.3 (VSS), D37.3 (VSS), D38.3 (VSS), D39.3 (VSS), D40.3 (VSS), D41.3 (VSS), D42.3 (VSS), D43.3 (VSS), D44.3 (VSS), D45.3 (VSS), D46.3 (VSS), D47.3 (VSS), D48.3 (VSS), D49.3 (VSS), D50.3 (VSS), J1.2, J5.1, J6.2, J7.5 (GND), J8.6, R2.3, S1.2B, S1.3B, S1.4B, U1.20 (GND), U2.2 (GND); also elsewhere on the board
LED_CONT: D39.2 (DOUT); also elsewhere on the board
LED_ROW0: D1.4 (DIN), J9.1, R1.1
MAG: U1.19 (PA3), U2.3 (OUTPUT)
unnamed: D1.2 (DOUT), D2.4 (DIN)
unnamed: D2.2 (DOUT), D3.4 (DIN)
unnamed: D3.2 (DOUT), D4.4 (DIN)
unnamed: D4.2 (DOUT), D5.4 (DIN)
unnamed: D5.2 (DOUT), D6.4 (DIN)
unnamed: D6.2 (DOUT), D7.4 (DIN)
unnamed: D7.2 (DOUT), D8.4 (DIN)
unnamed: D8.2 (DOUT), D9.4 (DIN)
unnamed: D10.2 (DOUT), D11.4 (DIN)
unnamed: D9.2 (DOUT), D10.4 (DIN)
unnamed: D11.2 (DOUT), D12.4 (DIN)
unnamed: D12.2 (DOUT), D25.4 (DIN)
unnamed: D13.2 (DOUT), D26.4 (DIN)
unnamed: D13.4 (DIN), D14.2 (DOUT), JP1.1 (A)
unnamed: D14.4 (DIN), D15.2 (DOUT)
unnamed: D15.4 (DIN), D16.2 (DOUT)
unnamed: D16.4 (DIN), D17.2 (DOUT)
unnamed: D17.4 (DIN), D18.2 (DOUT)
unnamed: D18.4 (DIN), D19.2 (DOUT)
unnamed: D19.4 (DIN), D20.2 (DOUT)
unnamed: D20.4 (DIN), D21.2 (DOUT)
unnamed: D21.4 (DIN), D22.2 (DOUT)
unnamed: D22.4 (DIN), D23.2 (DOUT)
unnamed: D23.4 (DIN), D24.2 (DOUT)
unnamed: D24.4 (DIN), D25.2 (DOUT)
unnamed: D26.2 (DOUT), D27.4 (DIN), JP1.2 (B)
unnamed: D27.2 (DOUT), D28.4 (DIN)
unnamed: D28.2 (DOUT), D29.4 (DIN)
unnamed: D29.2 (DOUT), D30.4 (DIN)
unnamed: D30.2 (DOUT), D31.4 (DIN)
unnamed: D31.2 (DOUT), D32.4 (DIN)
unnamed: D32.2 (DOUT), D33.4 (DIN)
unnamed: D33.2 (DOUT), D34.4 (DIN)
unnamed: D34.2 (DOUT), D35.4 (DIN)
unnamed: D35.2 (DOUT), D36.4 (DIN)
unnamed: D36.2 (DOUT), D37.4 (DIN)
unnamed: D37.2 (DOUT), D38.4 (DIN)
unnamed: D38.2 (DOUT), D50.4 (DIN)
unnamed: D39.4 (DIN), D40.2 (DOUT)
unnamed: D40.4 (DIN), D41.2 (DOUT)
unnamed: D41.4 (DIN), D42.2 (DOUT)
unnamed: D42.4 (DIN), D43.2 (DOUT)
unnamed: D43.4 (DIN), D44.2 (DOUT)
unnamed: D44.4 (DIN), D45.2 (DOUT)
unnamed: D45.4 (DIN), D46.2 (DOUT)
unnamed: D46.4 (DIN), D47.2 (DOUT)
unnamed: D47.4 (DIN), D48.2 (DOUT)
unnamed: D48.4 (DIN), D49.2 (DOUT)
unnamed: D49.4 (DIN), D50.2 (DOUT)
unnamed: R1.2, U1.5 (PA7)
PTC: J3.1, U1.11 (PB0)
RxD: J1.3, J2.1, J6.4, U1.8 (PB3)
SW1: S1.2A, U1.4 (PA6)
SW2: S1.3A, U1.3 (PA5)
SW3: S1.4A, U1.2 (PA4)
TxD: J1.4, J4.1, J6.3, U1.9 (PB2)
UPDI_DATA: J8.1, S1.1B, U1.16 (~RESET~/PA0)
USB_UPDI: J7.4 (ID), S1.1A

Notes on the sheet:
UPDI Programming Header
Note: 2018 Attiny3216/1616 data sheet lists 6 PTC in pinout table, but coversheet adverttises 12. Use latest Attiny3216/3217 ref: http://ww1.microchip.com/downloads/en/DeviceDoc/ATtiny3216-17-DataSheet-DS40002205A.pdf
Alt (2x more sensitive, costs more) DRV5053VAQDBZR 5 mT is strength of typical refrigerator magnet https://en.wikipedia.org/wiki/Orders_of_magnitude_(magnetic_field)
Power & Data Interlink Left/Right
Power & Data Interlink: Up/Down
USB Power Input
User Touch Input
Potentiometer Brighntess Adjust
Holes and Fiducials
Processor
LEDs: Rows 0 and 1
ROW 0
ROW 1
Hall Effect Sensor
DIP Switches
Development Test Point

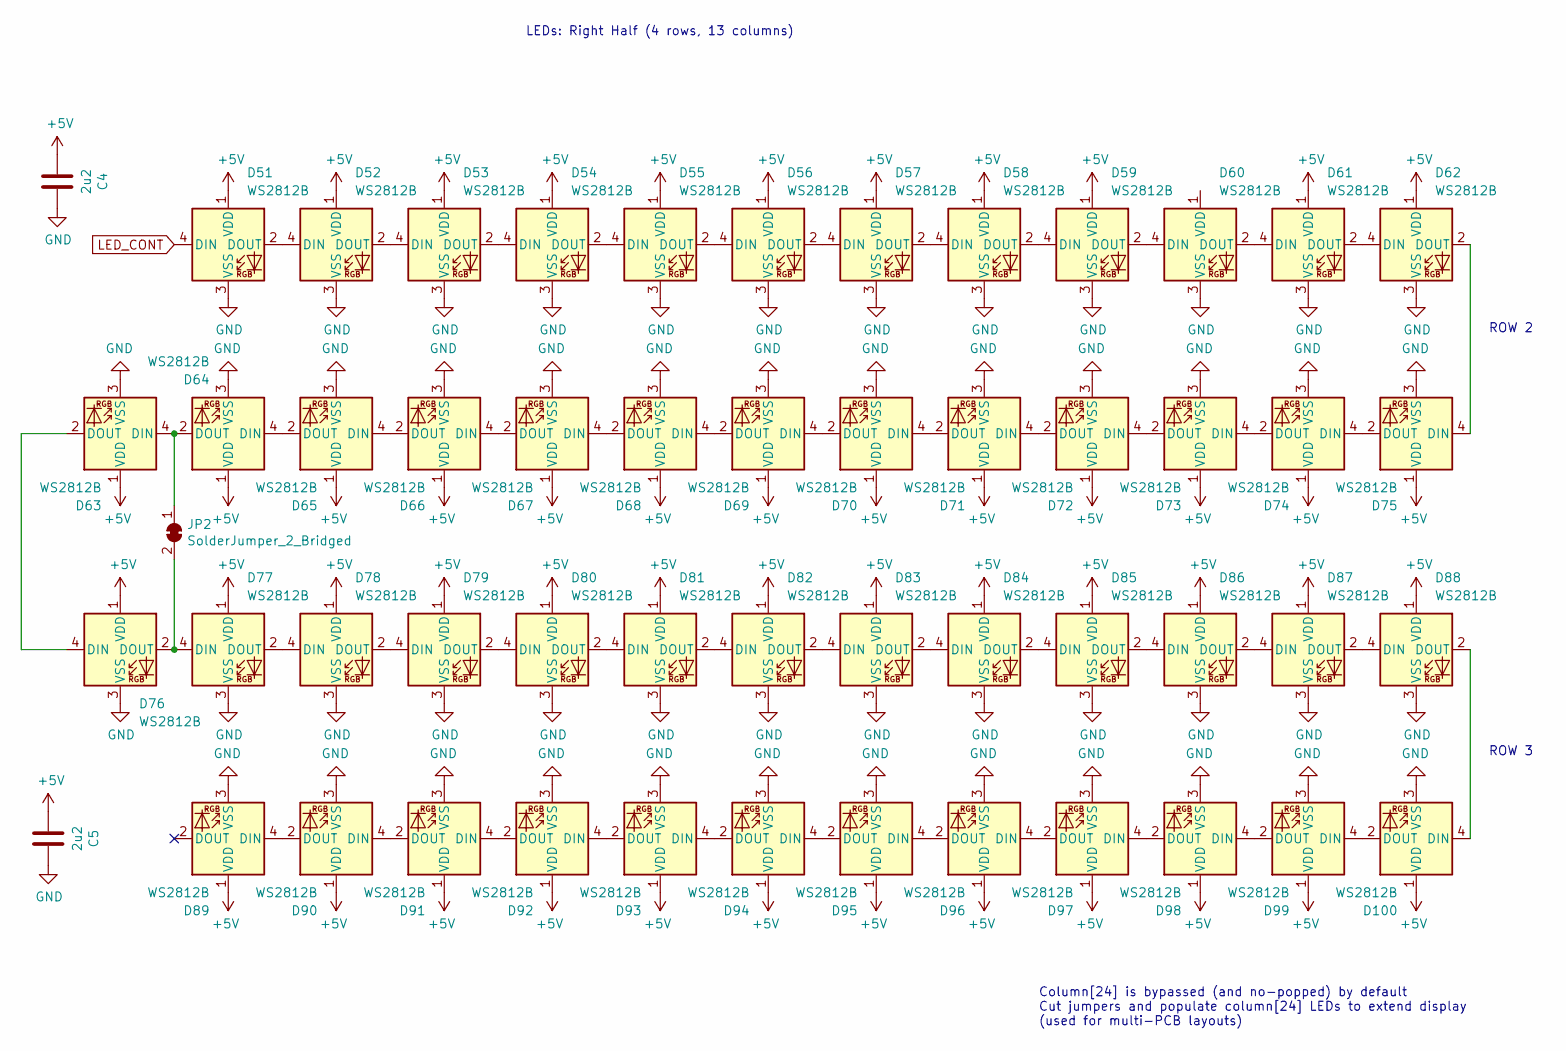
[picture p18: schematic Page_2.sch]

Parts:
C4, C5: 2u2; C_0805_2012Metric
D51, D52, D53, D54, D55, D56, D57, D58, D59, D60, D61, D62, D63, D64, D65, D66, D67, D68, D69, D70, D71, D72, D73, D74, D75, D76, D77, D78, D79, D80, D81, D82, D83, D84, D85, D86, D87, D88, D89, D90, D91, D92, D93, D94, D95, D96, D97, D98, D99, D100: WS2812B; LED_WS2812B_PLCC4_5.0x5.0mm_P3.2mm
JP2: SolderJumper_2_Bridged; SolderJumper-2_P1.3mm_Bridged_RoundedPad1.0x1.5mm

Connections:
+5V: C4.2, C5.2, D51.1 (VDD), D52.1 (VDD), D53.1 (VDD), D54.1 (VDD), D55.1 (VDD), D56.1 (VDD), D57.1 (VDD), D58.1 (VDD), D59.1 (VDD), D61.1 (VDD), D62.1 (VDD), D63.1 (VDD), D64.1 (VDD), D65.1 (VDD), D66.1 (VDD), D67.1 (VDD), D68.1 (VDD), D69.1 (VDD), D70.1 (VDD), D71.1 (VDD), D72.1 (VDD), D73.1 (VDD), D74.1 (VDD), D75.1 (VDD), D76.1 (VDD), D77.1 (VDD), D78.1 (VDD), D79.1 (VDD), D80.1 (VDD), D81.1 (VDD), D82.1 (VDD), D83.1 (VDD), D84.1 (VDD), D85.1 (VDD), D86.1 (VDD), D87.1 (VDD), D88.1 (VDD), D89.1 (VDD), D90.1 (VDD), D91.1 (VDD), D92.1 (VDD), D93.1 (VDD), D94.1 (VDD), D95.1 (VDD), D96.1 (VDD), D97.1 (VDD), D98.1 (VDD), D99.1 (VDD), D100.1 (VDD); also elsewhere on the board
GND: C4.1, C5.1, D51.3 (VSS), D52.3 (VSS), D53.3 (VSS), D54.3 (VSS), D55.3 (VSS), D56.3 (VSS), D57.3 (VSS), D58.3 (VSS), D59.3 (VSS), D60.3 (VSS), D61.3 (VSS), D62.3 (VSS), D63.3 (VSS), D64.3 (VSS), D65.3 (VSS), D66.3 (VSS), D67.3 (VSS), D68.3 (VSS), D69.3 (VSS), D70.3 (VSS), D71.3 (VSS), D72.3 (VSS), D73.3 (VSS), D74.3 (VSS), D75.3 (VSS), D76.3 (VSS), D77.3 (VSS), D78.3 (VSS), D79.3 (VSS), D80.3 (VSS), D81.3 (VSS), D82.3 (VSS), D83.3 (VSS), D84.3 (VSS), D85.3 (VSS), D86.3 (VSS), D87.3 (VSS), D88.3 (VSS), D89.3 (VSS), D90.3 (VSS), D91.3 (VSS), D92.3 (VSS), D93.3 (VSS), D94.3 (VSS), D95.3 (VSS), D96.3 (VSS), D97.3 (VSS), D98.3 (VSS), D99.3 (VSS), D100.3 (VSS); also elsewhere on the board
LED_CONT: D51.4 (DIN); also elsewhere on the board
unnamed: D51.2 (DOUT), D52.4 (DIN)
unnamed: D52.2 (DOUT), D53.4 (DIN)
unnamed: D53.2 (DOUT), D54.4 (DIN)
unnamed: D54.2 (DOUT), D55.4 (DIN)
unnamed: D55.2 (DOUT), D56.4 (DIN)
unnamed: D56.2 (DOUT), D57.4 (DIN)
unnamed: D57.2 (DOUT), D58.4 (DIN)
unnamed: D58.2 (DOUT), D59.4 (DIN)
unnamed: D59.2 (DOUT), D60.4 (DIN)
unnamed: D60.2 (DOUT), D61.4 (DIN)
unnamed: D61.2 (DOUT), D62.4 (DIN)
unnamed: D62.2 (DOUT), D75.4 (DIN)
unnamed: D63.2 (DOUT), D76.4 (DIN)
unnamed: D63.4 (DIN), D64.2 (DOUT), JP2.1 (A)
unnamed: D64.4 (DIN), D65.2 (DOUT)
unnamed: D65.4 (DIN), D66.2 (DOUT)
unnamed: D66.4 (DIN), D67.2 (DOUT)
unnamed: D67.4 (DIN), D68.2 (DOUT)
unnamed: D68.4 (DIN), D69.2 (DOUT)
unnamed: D69.4 (DIN), D70.2 (DOUT)
unnamed: D70.4 (DIN), D71.2 (DOUT)
unnamed: D71.4 (DIN), D72.2 (DOUT)
unnamed: D72.4 (DIN), D73.2 (DOUT)
unnamed: D73.4 (DIN), D74.2 (DOUT)
unnamed: D74.4 (DIN), D75.2 (DOUT)
unnamed: D76.2 (DOUT), D77.4 (DIN), JP2.2 (B)
unnamed: D77.2 (DOUT), D78.4 (DIN)
unnamed: D78.2 (DOUT), D79.4 (DIN)
unnamed: D79.2 (DOUT), D80.4 (DIN)
unnamed: D80.2 (DOUT), D81.4 (DIN)
unnamed: D81.2 (DOUT), D82.4 (DIN)
unnamed: D82.2 (DOUT), D83.4 (DIN)
unnamed: D83.2 (DOUT), D84.4 (DIN)
unnamed: D84.2 (DOUT), D85.4 (DIN)
unnamed: D85.2 (DOUT), D86.4 (DIN)
unnamed: D86.2 (DOUT), D87.4 (DIN)
unnamed: D87.2 (DOUT), D88.4 (DIN)
unnamed: D89.4 (DIN), D90.2 (DOUT)
unnamed: D90.4 (DIN), D91.2 (DOUT)
unnamed: D91.4 (DIN), D92.2 (DOUT)
unnamed: D92.4 (DIN), D93.2 (DOUT)
unnamed: D93.4 (DIN), D94.2 (DOUT)
unnamed: D94.4 (DIN), D95.2 (DOUT)
unnamed: D95.4 (DIN), D96.2 (DOUT)
unnamed: D96.4 (DIN), D97.2 (DOUT)
unnamed: D97.4 (DIN), D98.2 (DOUT)
unnamed: D98.4 (DIN), D99.2 (DOUT)
unnamed: D99.4 (DIN), D100.2 (DOUT)
unnamed: D88.2 (DOUT), D100.4 (DIN)

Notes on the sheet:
Column[24] is bypassed (and no-popped) by default Cut jumpers and populate column[24] LEDs to extend display (used for multi-PCB layouts)
LEDs: Right Half (4 rows, 13 columns)
ROW 2
ROW 3

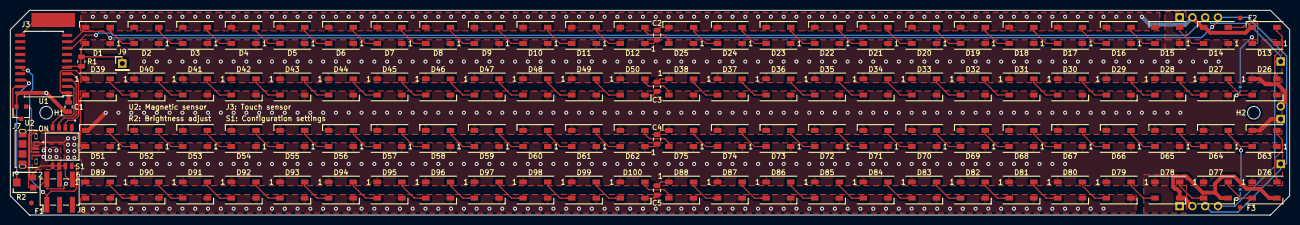
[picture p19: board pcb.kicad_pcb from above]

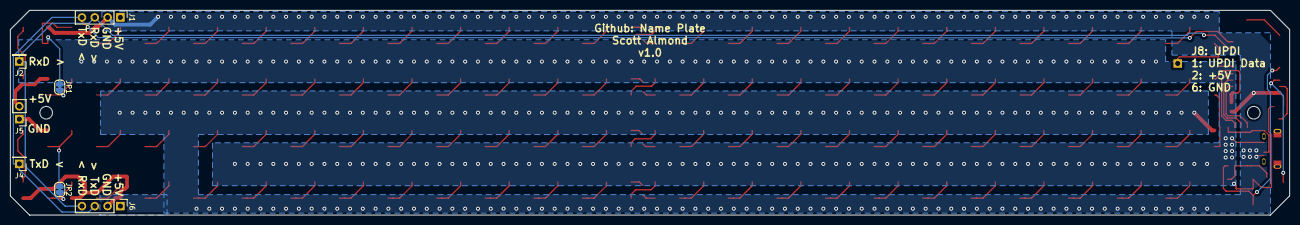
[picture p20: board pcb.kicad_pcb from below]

Board: 2 copper layers, 254.0 x 40.6 mm, 126 parts (7 on the bottom side), 113 nets.

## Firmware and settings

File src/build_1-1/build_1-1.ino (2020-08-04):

//TODO:  Setup instructions


// ---- Libraries ----
// -- LEDs --
#include <Adafruit_NeoPixel.h>
#ifdef __AVR__
 #include <avr/power.h> // Required for 16 MHz Adafruit Trinket
#endif

#include <EEPROM.h>

// -- Top Level IO --
const bool SKIP_BOOT=true; //if skip boot, then jump straight to first shapter without strip test
const byte PIN_LED=PIN_PA7;//D1 is physical pin 6
const byte LED_ROWS=4;
const byte LED_COLS=24;
const byte LED_COUNT=LED_ROWS*LED_COLS;//note: max 255 LEDs in byte
neoPixelType STRIP_TYPE=NEO_GRBW + NEO_KHZ800;
Adafruit_NeoPixel strip = Adafruit_NeoPixel(LED_COUNT, PIN_LED, STRIP_TYPE);
const byte DEFAULT_BRIGHTNESS=16;
const byte MIN_BRIGHTNESS=4;
const byte MAX_BRIGHTNESS=255;
const byte BOOT_CHAPTER_EEPROM_ADDRESS=0;
const byte ANALOG_AVERAGE=32;//number of user input brightness readings to average to form final displayed brightness
//PRECON: BRIGHTNESS_AVERAGE readings will be taken before exiting from boot.  Otherwise brightness will
//default to less and display may appear dim or black
byte brightness_index=0;//index of the next brightness reading.
word brightness_measurements[ANALOG_AVERAGE];
const byte MAGNET_THRESHOLD=16;//counts (LSB = 5V/1024) that the
//magnetic measurement needs to change from the boot-up value before a user command is registered
int magnetic_average=0;//average magnetic reading, calibrated at boot up
const word MAGNET_STATE_CHANGE_MS=512;//collect user input for this long before changing state
unsigned long magnet_timestamp_ms=0;//time the user started changing the device state
byte magnet_previous_state=0;//state that the user is trying to update the device to

// -- User IO --
const byte PIN_TOUCH=PIN_PB0;//periphreal touch controller button
const byte PIN_MAGNET=PIN_PA3;
const byte PIN_BRIGHTNESS=PIN_PA2;
const byte PIN_CONFIG_UPDATE_DAILY=PIN_PA6;//SW2 on DIP switch
const byte PIN_CONFIG_DIAGNOSTIC=PIN_PA5;//SW3 on DIP switch
const byte PIN_CONFIG_TESSELLATE=PIN_PA4;//SW4 on DIP switch

// ---- State Machines ----
// -- Book --
//The program is structured like a book where there is an introduction "setup()"
//followed by reading page after page (frame render) in each chapter "loop()"
#define CHAPTER_ERROR 254
#define CHAPTER_STRIP_TEST 255
#define CHAPTER_MONOCHROME 0
#define CHAPTER_RAINBOW 1
#define CHAPTER_RAINBOW_RIPPLE 2
#define CHAPTER_SCATTER_RAINBOW 3
#define CHAPTER_SCATTER_BLINK 4
#define CHAPTER_FIREWORKS 5
#define CHAPTER_MATRIX_RAIN 6
#define CHAPTER_LIFE 7
#define CHAPTER_SNAKE 8 // consider refactor with multiple snake - white background washes out snake.  also see issue with snake going over its own tail
#define CHAPTER_PORTAL 99
#define CHAPTER_METEOR 9
#define CHAPTER_CHRISTMAS 10
#define CHAPTER_FLAG_AMERICAN 11 //to do twinkling, every pixel must flicker https://www.shutterstock.com/video/clip-22198711-loopable-animation-landscape-showing-four-seasons-each
const byte LAST_CHAPTER=CHAPTER_FLAG_AMERICAN;//highest indexed chapter in the book
byte chapter_id=CHAPTER_STRIP_TEST; //set to 255 to run LED check at boot, set to 0 to skip
bool is_go_to_new_chapter=false;//private flag used for tracking state change to new chapter
unsigned long chapter_timestamp_ms=0;//used for various chapter state machines.  Note wrap over after ~50 days
byte led_state[LED_ROWS][LED_COLS];//general-purpose state machine allocation for all chapters to share
unsigned long book_frame_number=0;//number of iterations through the current loop

//todo: future
//balls bouncing: ref https://www.youtube.com/watch?v=VAa4duqMrgs
//*lava lamp
//consdier star field exploring from center https://www.youtube.com/results?search_query=1990s+screen+saver
//consdier moving checkerboard https://www.youtube.com/watch?v=VUUJVDGda-I&feature=youtu.be&t=197
//*consider generic fire animation https://www.youtube.com/watch?v=_KhtBA0EHDM
//note: built in map function may be used to mix colors
//consider swirling effect https://www.pond5.com/stock-footage/item/1103915-fractal-form-background-visuals-hd
//x issue with brightness dimming is finite 8-bit depth https://www.shutterstock.com/video/clip-1866235-led-lights-seamless-looping-animation
//multiple snakes could follow fixed pattern https://www.youtube.com/watch?v=iG9JrUzcgCY
//*portal, yellow left, blue right https://www.reddit.com/r/Rainmeter/comments/h8ewx5/dual_monitor_suit_inspired_by_the_portal/
// juxtapose with matrix rain
//consider involved pattern https://www.enviral-design.com/led-array-3d-printed-light-diffuse-rails/
//*debug screen (human readable?)
//  internal voltage
//  internal temperature
//  time counter
//  user input: switches, magnet (not really accessible...), brightness
//consider snake wrap left/right but NOT up/down
//consider snake prefer East far more than West (if west, higher prob of change)

// -- Chapter --
// - Snake - 
byte snake_row=0;//position of head
byte snake_col=0;
const byte STATE_SNAKE_STEP_FORWARD=4;//32;//when the stake body part state goes from this 0 up to this point, step the snake forward one pixel
byte snake_dir=B00000100;//8 bit array: lowest 4 bits are previous direction MSB < North/East/South/West > LSB

void setup() {
  pinMode(PIN_LED, OUTPUT);
  pinMode(PIN_MAGNET,INPUT);
  pinMode(PIN_BRIGHTNESS,INPUT);
  pinMode(PIN_CONFIG_UPDATE_DAILY,INPUT_PULLUP);
  pinMode(PIN_CONFIG_DIAGNOSTIC,INPUT_PULLUP);
  pinMode(PIN_CONFIG_TESSELLATE,INPUT_PULLUP);
  //strip.begin();
  //strip.setBrightness(DEFAULT_BRIGHTNESS);
  //strip.clear();
  //strip.show();
  chapter_timestamp_ms=millis();
  setupMagnet();
  setupMagnet();//second run to allow analog to settle after LED write (not sure if value-added, but is quick to execute)
}

//state machine that executes every frame of the animation:
//1. render the frame of the current chapter
//2. flush frame buffer to LEDs
//3. update the chapter if the current chapter has finsihed or if the user provides input
void loop() {
  bool is_booted=false;
  switch(chapter_id)
  {//note the order the chapters are executed is determined by the value of the globally defined constants, not the order in this switch case
    case CHAPTER_STRIP_TEST: is_booted=strip_test(is_go_to_new_chapter); break;
    case CHAPTER_MONOCHROME: monochrome(is_go_to_new_chapter); break;
    case CHAPTER_RAINBOW: rainbow(is_go_to_new_chapter); break;
    case CHAPTER_SCATTER_BLINK: scatter_blink(is_go_to_new_chapter); break;
    case CHAPTER_SCATTER_RAINBOW: scatter_rainbow(is_go_to_new_chapter); break;
    case CHAPTER_SNAKE: snake(is_go_to_new_chapter); break;
    case CHAPTER_RAINBOW_RIPPLE: rainbow_ripple(is_go_to_new_chapter); break;
    case CHAPTER_MATRIX_RAIN: matrix_rain(is_go_to_new_chapter,book_frame_number); break;
    case CHAPTER_FLAG_AMERICAN: flag_american(is_go_to_new_chapter); break;
    case CHAPTER_FIREWORKS: fireworks(is_go_to_new_chapter); break;
    case CHAPTER_PORTAL: portal(is_go_to_new_chapter); break;
    case CHAPTER_LIFE: life(is_go_to_new_chapter); break;
    case CHAPTER_METEOR: meteor(is_go_to_new_chapter); break;
    case CHAPTER_CHRISTMAS: generic_blink(is_go_to_new_chapter,3); break;
    default: error(is_go_to_new_chapter); break;//any unpopulated (no case statement) chapters are replaced with error display.  Add a chapter_id++; here to hto fix the issue
  }
  updateChapter(is_booted);
}

// ---- Helper Methods ----
//given pixel ID, get the corresponding row within the display matrix
byte getRow(byte iter)
{
  return iter/LED_COLS;
}

byte getCol(byte iter)
{
  return (getRow(iter)%2) ? (LED_COLS-(iter%LED_COLS)-1) : (iter%LED_COLS);//counting reverses row-to-row
}

// ---- Chapter Navigation, User IO ----
//while user input, display red/green depending on strength of user input
//if more than X seconds of contiguous input, then change +- chapter
void updateChapter(bool is_booted)
{
  book_frame_number++;//update frame counter every frame
  byte chapter_delta=updateMagnet();
  displayMagnet();
  updateBrightness();
  strip.show();
  //is_done |= check user input
  if(is_booted)
  {
    chapter_id=getBootChapter();//++;
    is_go_to_new_chapter=true;
  }
  else if(chapter_delta!=0)//if user input, then inc/dec chapter index
  {
    if(chapter_id==0 && chapter_delta==255) chapter_id=LAST_CHAPTER;
    else{
      chapter_id+=chapter_delta;
      chapter_id%=LAST_CHAPTER+1;//break into two lines - note compiler may alter order of operations?
    }
    is_go_to_new_chapter=true;
    setBootChapter(chapter_id);
  }else is_go_to_new_chapter=false;
  if(millis()<chapter_timestamp_ms) chapter_timestamp_ms=0;//brute force fix to remedy 50 day wrap around...
}

bool isBooting()
{
  return chapter_id==CHAPTER_ERROR || chapter_id==CHAPTER_STRIP_TEST;
}

//allow for user input on brightness
void updateBrightness()
{//getBrightness already declared in neoPixel library
  byte brightness_setting=getInputBrightness();
  //displayDebug(brightness_setting/4);
  //displayDebug(chapter_id);
  //displayDebug(getBootChapter());
  strip.setBrightness(brightness_setting);
}

byte getInputBrightness()
{
  //pre-empteively fill analog readings so an average can be taken later when out of boot mode
  brightness_measurements[brightness_index]=1024-analogRead(PIN_BRIGHTNESS);//10 bit reading - prefer CW to increase brightness
  brightness_index++;
  brightness_index%=ANALOG_AVERAGE;
  if(isBooting())
    return DEFAULT_BRIGHTNESS;//static setting during boot
  //allow for more complicated user IO once out of boot
  long brightness_setting=0;
  for(byte iter=0;iter<ANALOG_AVERAGE;iter++)
  {
    brightness_setting+=brightness_measurements[brightness_index];
  }
  brightness_setting>>=2;//convert square of 10-bit values to 8-bit value
  brightness_setting/=ANALOG_AVERAGE;//convert sum to average by dividing by number of samples
  brightness_setting=brightness_setting*brightness_setting;//square brightness is approximation of user logarithmic perception
  brightness_setting>>=8;//re-scale to 8-bit range "square root"
  
  brightness_setting=max(MIN_BRIGHTNESS,brightness_setting);
  brightness_setting=min(MAX_BRIGHTNESS,brightness_setting);
  return brightness_setting;
}

//call once on boot
void setupMagnet()
{
  magnetic_average=0;
  for(byte iter=0;iter<ANALOG_AVERAGE;iter++) magnetic_average+=analogRead(PIN_MAGNET);
  magnetic_average/=ANALOG_AVERAGE;
}

void displayMagnet()
{
  if(magnet_previous_state==0) return;//no visualization if no change in state
  float threshold=(millis()-magnet_timestamp_ms)/(1.0*MAGNET_STATE_CHANGE_MS);
  threshold=(0+(LED_COLS/4))*threshold;
  for(byte iter=0;iter<LED_COUNT;iter++)
  {
    byte row=getRow(iter);
    byte col=getCol(iter);
    bool is_red=magnet_previous_state>128;
    if(col<(LED_COLS/4))
    {
      if(col>threshold) strip.setPixelColor(iter,strip.Color(is_red?255:0,is_red?0:255,0,0));
      else strip.setPixelColor(iter,strip.Color(0,0,0,0));
      /*if(row<(LED_ROWS/2))
      {
        //if(col<(LED_COLS/4)*
        float threshold=(millis()-magnet_timestamp_ms)/(1.0*MAGNET_STATE_CHANGE_MS);
        threshold=(0+(LED_COLS/4))*threshold;
        if(col<threshold && !is_red) strip.setPixelColor(iter,strip.Color(0,255,0,0));
        else if(((LED_COLS/4)-col)>threshold && is_red) strip.setPixelColor(iter,strip.Color(255,0,0,0));
        else strip.setPixelColor(iter,strip.Color(0,0,0,0));
      }else
        strip.setPixelColor(iter,strip.Color(is_red?255:0,is_red?0:255,0,0));
      */
    }
  }
}

//1 for ++ chapter, 255 for -- chapter
byte updateMagnet()
{
  if(isBooting()) return 0;//note: WAS return;, SHOULD HAVE BEEN return 0;
  //was returning garbage value, messing with boot sequence and EEPROM booted chapter value
  byte next_state=0;
  if((analogRead(PIN_MAGNET)-magnetic_average)>MAGNET_THRESHOLD) next_state=1;
  if((magnetic_average-analogRead(PIN_MAGNET))>MAGNET_THRESHOLD) next_state=255;
  if(next_state!=magnet_previous_state)
  {
    magnet_previous_state=next_state;
    magnet_timestamp_ms=millis();//start timer ticking
  }
  unsigned long delta_ms=millis()-magnet_timestamp_ms;
  if(delta_ms>(1<<12)) delta_ms=0;//assume user input<1 hour, ignore errors when millis() wraps over
  if(delta_ms>MAGNET_STATE_CHANGE_MS)
  {
    magnet_timestamp_ms=millis();
    magnet_previous_state=0;//set state back to default
    return next_state;
  }
  return 0;//no state change
}

//after power cycle, return the device to the last commanded chapter
byte getBootChapter()
{
  byte boot_chapter=EEPROM.read(BOOT_CHAPTER_EEPROM_ADDRESS);
  if(boot_chapter==CHAPTER_STRIP_TEST) return 0;
//return CHAPTER_LIFE;//zzstophere
  boot_chapter%=(LAST_CHAPTER+1);//ensure selected boot chapter is within range of permissable chapters
  return boot_chapter;
}

//each time the user changes the chapter, save state to be fetched at next boot
void setBootChapter(byte boot_chapter)
{
  delay(100);//debug safety check to avoid high speed IO to EEPROM (limited write cycles)
  if(boot_chapter<=LAST_CHAPTER)//only save valid chapters - skip boot and error cases
    EEPROM.put(BOOT_CHAPTER_EEPROM_ADDRESS,boot_chapter);
}

void displayDebug(byte val)
{
  for(byte iter=0;iter<LED_COUNT;iter++)
  {
    bool is_green=iter<val;
    bool is_red=!is_green;
    strip.setPixelColor(iter, strip.Color(is_red?255:0,is_green?255:0,0,0));
  }
  strip.show();
}

// ---- Animations ----
//boot-up animation to allow the user to verify the proper operation of all LEDs
//red, green, blue, white flash on all LEDs
bool strip_test(bool is_new_chapter)
{
  byte led_color=(millis()-chapter_timestamp_ms)/512;//change color every x milliseoncds
  if(led_color>=4 || SKIP_BOOT) return true;
  strip.fill(strip.Color(led_color==0?255:0,
                         led_color==1?255:0,
                         led_color==2?255:0,
                         led_color==3?255:0),0,LED_COUNT);
  return false;
}

//hold a static white color
void monochrome(bool is_new_chapter)
{
  //strip.fill(strip.Color(millis()%8,0,millis()%8),0,LED_COUNT);
  strip.fill(strip.gamma32(strip.Color(0,105,176,0)),0,LED_COUNT);
  //strip.fill(strip.Color(0,105,176),0,LED_COUNT);
}

//display a static pattern where the display is broken into vertical quarters by color
void error(bool is_new_chapter)
{
  for(byte iter=0;iter<LED_COUNT;iter++)
  {//left to right quarters of display: white, red, green, blue
    byte col=getCol(iter);
    /*bool is_red=col<(LED_COLS/4);
    bool is_green=!is_red && (col<(LED_COLS/2));
    bool is_blue= !is_red && !is_green && (col<(3*(LED_COLS/4)));
    bool is_white=!is_red && !is_green && !is_blue;*/
    bool is_white=col<(LED_COLS/4);
    bool is_red=  !is_white && (col<(LED_COLS/2));
    bool is_green=!is_white && !is_red && (col<(3*(LED_COLS/4)));
    bool is_blue= !is_white && !is_red && !is_green;
    strip.setPixelColor(iter, strip.Color(is_red?255:0,
                                          is_green?255:0,
                                          is_blue?255:0,
                                          is_white?255:0));
  }
}

//all LEDs cycle smoothly though the rainbow  red --> green --> blue
void rainbow(bool is_new_chapter)
{
  uint16_t hue=millis();//*8;//set higher multiplication to cycle LEDs faster.  *16 is cycling full rainbow every ~8 seconds
  uint8_t  sat = 255;
  uint8_t  val = 255;
  strip.fill(strip.gamma32(strip.ColorHSV(hue, sat, val)),0,LED_COUNT);
}

//inspired by:
//  https://www.adafruit.com/product/3444 demo pattern
//sinusoid magnitude is mapped to LED hue
void rainbow_ripple(bool is_new_chapter)
{
  int phase_tms_period=8191*2;//(1<<13);
  float phase_tms=(PI*2*(millis()%phase_tms_period))/phase_tms_period;
  //int time_reversal_period=(1<<14)+(1<<10)+(1<<7);
  //float time_reversal_phase=(PI*2*(millis()%time_reversal_period))/time_reversal_period;
  int time_reversal_period_1=11633;//(1<<14);//+(1<<10);
  int time_reversal_period_2=33529;//(1<<15);//+(1<<9);
  float time_reversal_phase_1=(PI*2*(millis()%time_reversal_period_1))/time_reversal_period_1;
  float time_reversal_phase_2=0.5*(PI*2*(millis()%time_reversal_period_2))/time_reversal_period_2;
  float time_reversal_phase=(sin(time_reversal_phase_1)+sin(time_reversal_phase_2))*PI;
  //phase_tms=sin(phase_tms)*PI;
  int spread_period=25679;//time_reversal_period_1*2;//(1<<14)+(1<<13);
  float spread=2*sin(PI+PI*2*(millis()%spread_period)/spread_period);
  for(byte iter=0;iter<LED_COUNT;iter++)
  {
    byte row=getRow(iter);
    byte col=getCol(iter);
    float phase_x=(PI*2*col)/(LED_COLS*(3+spread));
    float temp=sin(phase_x+phase_tms+time_reversal_phase);
    //float hue_sin=(temp<0?-1:1)*temp*temp*0.5+0.5;//clip to 0-1
    float hue_sin=sin(phase_x+phase_tms+time_reversal_phase)*0.5+0.5;//clip to 0-1
    uint16_t hue=0xFFFF*hue_sin;
    uint8_t  sat = 255;
    uint8_t  val = 255;
    strip.setPixelColor(iter,strip.gamma32(strip.ColorHSV(hue, sat, val)));
  }
}

//move pixels left to right while slowly changing hue across columns
//ref https://www.kickstarter.com/projects/macetech/rgb-led-shades?ref=discovery_category
void scatter_rainbow(bool is_new_chapter)
{
  for(byte iter=0;iter<LED_COUNT;iter++)
  {
    byte row=getRow(iter);
    byte col=getCol(iter);
    if(is_new_chapter) led_state[row][col]=random(255);
    byte count_down_timer_max=32;
    if(col==0)
    {
      if(!random(48) && !led_state[row][col]) led_state[row][col]=count_down_timer_max;
    }else{
      if(led_state[row][col-1]==1) led_state[row][col]=count_down_timer_max;
    }
    if(led_state[row][col]>0) led_state[row][col]--;
    bool is_off=led_state[row][col]==0||(led_state[row][col]==count_down_timer_max && row%2==1);//<128;
    uint16_t hue=(millis()*8)-(col<<9);//set higher multiplication factor to cycle color faster.  *16 is cycling full rainbow every ~8 seconds
    uint8_t  sat = 255;
    uint8_t  val = 255;
    strip.setPixelColor(iter,is_off?0:strip.gamma32(strip.ColorHSV(hue, sat, val)));
  }
}

//illuminate LEDs for a random period of time
//https://www.youtube.com/watch?v=H1k7mxhWQ5Q
void scatter_blink(bool is_new_chapter)
{
  generic_blink(is_new_chapter,0);
}

//allow for multiple configurations of colors
//mode = 0, slowly changing blinking rainbow on black background
//mode = 1, slowly changing blinking rainbow on white background
//mode = 2, orange/purple halloween colors
//mode = 3, red/green/white christmas colors
void generic_blink(bool is_new_chapter,byte mode)
{
  byte color_count=2;
  uint32_t color_1=strip.gamma32(strip.ColorHSV(millis(), 255, 255));//slowly changing rainbwo color
  uint32_t color_2=strip.Color(0,0,0,0);
  uint32_t color_3=strip.Color(0,0,0,0);
  switch(mode)
  {
    default: break;
    case 1:
      color_2=strip.Color(0,0,0,255);
    break;
    case 2:
      color_1=strip.gamma32(strip.Color(255,165,0,0));
      color_2=strip.gamma32(strip.Color(255,0,255,0));
    break;
    case 3:
      color_count=3;
      color_1=strip.Color(255,0,0,0);
      color_2=strip.Color(0,255,0,0);
      color_3=strip.Color(255,255,255,255);
     break;
  }
  for(byte iter=0;iter<LED_COUNT;iter++)
  {
    byte row=getRow(iter);//iter/LED_COLS;
    byte col=getCol(iter);//iter%LED_COLS;
    byte my_cycle;
    if(is_new_chapter)
    {
      byte max_cycle=255;
      byte min_cycle=128;
      byte my_cycle=random(min_cycle,max_cycle);
      led_state[row][col]=my_cycle;
    }
    my_cycle=led_state[row][col];
    byte my_state=(millis()/(color_count==2?4:16))%my_cycle;
    bool is_color_1=my_state<(my_cycle/color_count);
    bool is_color_2=(my_state/2)<(my_cycle/color_count);
    if(is_color_1) strip.setPixelColor(iter, color_1);
    else if((color_count==2 && !is_color_1) || is_color_2) strip.setPixelColor(iter, color_2);
    else strip.setPixelColor(iter, color_3);
  }
}

//allow for groups of LEDs to move horizontally as one
//https://www.youtube.com/watch?v=H1k7mxhWQ5Q
void strip_blink(bool is_new_chapter)
{
  
}

//orange animation along bottom in front of blue sky, occasional lightening
//orange "circles" (groups of 2 pixels) animate from one zie to the other
void halloween(bool is_new_chapter)
{
  for(byte iter=0;iter<LED_COUNT;iter++)
  {
    byte row=getRow(iter);//iter/LED_COLS;
    byte col=getCol(iter);//iter%LED_COLS;
    if(is_new_chapter)
    {
      if(row==0) led_state[row][col]=0;
      //else if(row==4) led_state[row][col]=;
    }
  }
}
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

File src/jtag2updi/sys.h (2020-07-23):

/*
 * sys.h
 *
 * Created: 02-10-2018 13:07:18
 *  Author: JMR_2
 */

#ifndef SYS_H_
#define SYS_H_

#include <avr/io.h>
#include <string.h>
#include <stdio.h> // for size_t
#include "parts.h"

//Disable the response signature during burst writes to permit faster writes
#define NO_ACK_WRITE

// Disable the host timeout - this is required for use with avrdude in terminal mode (-t)
// but with this disabled, can get "stuck" if communication with host is interrupted at 115200 baud
// as avrdude on next start will try to communicate at 19200 baud. Reset is required to fix this.
// Potential enhancement - if this is set, while waiting for message from host, ALSO count transitions on the RX pin
// If we see a bunch of transitions, but no received characters, we know the host is using the wrong baud rate, and
// so, switch back to 19200 baud.
//#define DISABLE_HOST_TIMEOUT

// Disable the timeout waiting for response from target. Probablty not necessary to set. With this disabled, if the target is expected to respond
// but does not, jtag2updi will get stuck waiting for it.

//#define DISABLE_TARGET_TIMEOUT

// this will include the SIB, deduced NVM version, and silicon revision in early responses to SET_DEVICE_DESCRIPTPOR (for SIB and NVM version) and ENTER_PROGMODE (for silicon rev)
#define INCLUDE_EXTRA_INFO_JTAG


// Auxiliary Macros
#define CONCAT(A,B) A##B
//#define CONCAT3(A,B,C) A##B##C
#if (__AVR_ARCH__ == 103) || (__AVR_ARCH__ == 104)
//We'll call these ones XAVR for purposes of defines, instead of XTINY. This encompases megaAVR 0-series and DA-series parts

	#define XAVR
	#	define PIN(x) CONCAT(VPORT,x).IN
	#	define PORT(x) CONCAT(VPORT,x).OUT
	#	define DDR(x) CONCAT(VPORT,x).DIR
//	# define PULLUP_ON(x,y) CONCAT(PORT,x).CONCAT3(PIN,y,CTRL)=0x04
//	# define PULLUP_OFF(x,y) CONCAT(PORT,x).CONCAT3(PIN,y,CTRL)=0x04

#else

	#	define PIN(x) CONCAT(PIN,x)
	#	define PORT(x) CONCAT(PORT,x)
	#	define DDR(x) CONCAT(DDR,x)

#endif

/* User Configuration goes up here - the rest down below is defaults that you can override
   or stuff that is hardware specific   */

#if defined(__AVR_ATtiny_Zero_One__)
	// tinyAVR 0-series and 1-series parts
	// 3216, 1604, that kind of thing

	#define LED_PORT A
	#define LED_PIN 7

	// Second LED is used to indicate NVM version, or as an additional debugging aid.
	#define LED2_PORT A
	#define LED2_PIN 6

  //USARTDEBUG not practical here because only one UART.
//	#define USE_SPIDEBUG

  //SPIPRESC sets prescaler of SPI clock - it can go *INSANELY* fast, such that very little could keep up with it.

  #define SPIPRESC (SPI_CLK2X_bm|SPI_PRESC1_bm)


#elif defined( __AVR_ATmega_Mighty__ )
	// For ATmega16, ATmega32, and the later x4 parts (up to the 1284P).
	// On the ones with two USARTS, you can use USART debugging.
	//
	// Here USART debug output is an option too
	// at least on parts with the second USART
	// You should be able to hit 2MBaud with F_CPU=16000000 and DEBUG_BAUDVAL 0 or 1mbaud with 1 if your serial adapter can't handle that.
	// At 20, though, on classic AVRs, you're out of luck unless you have an adapter that can do 2.5 mbaud...have to go all the way down to 500kbaud (DEBUG_BAUDVAL 4) to divide it to something common.. Good thing almost everyone runs them at 16.
	// #define USE_USARTDEBUG
	// #define DEBUG_BAUDVAL 0




#elif defined (__AVR_ATmega_Mini__) || defined(ARDUINO_AVR_LARDU_328E)
	// For ATmega328 and 168 (P, PB) parts
	// Same deal as before/ Remember that the buildin LED is on the same pin as SCK on most boards, so you'll want to cadd LEDs on other pinn, defaults to D2
	// On PB parts can also use second USART. Using the second SPI is not supported.


	//#define USE_SPIDEBUG
	//#define SPIPRESC (0x05)



#elif defined (__AVR_ATmega_Mega__)
	// 2560 and that family, like the ones used on the Arduino Mega
	// Same as the others with extra USARTS, only here you can specify which one if you must
	// #define USE_USARTDEBUG
	// #define DEBUG_USART 2
	// Can even change the host USART if you want


#elif defined (__AVR_ATmega_Zero__ ) || defined( __AVR_DA__)
// 4808, 4809. and the rest of the megaAVR 0-series
// Same as above, pretty much
// big difference here is your specify the name of the peripheral instead of the number, and the target baud rate, because we grab the OSCCAL value per datasheet./
//	#define USE_USARTDEBUG
//	#define DEBUG_USART USART1
//	#define DEBUG_BAUDRATE 2000000UL

#endif


/* Defaults and hardware-specific stuff 								*/
/* Shouldn't need to change anything here 							*/
/* IF you want to override, copy it to the blocks above */


#if defined(__AVR_ATtiny_Zero_One__)
// tinyAVR 0-series and 1-series parts

	#	ifndef UPDI_PORT
	#		define UPDI_PORT B
	#	endif

	#	ifndef UPDI_PIN
	#		define UPDI_PIN 0
	#	endif

	#	ifndef LED_PORT
	#		define LED_PORT B
	#	endif

	#	ifndef LED_PIN
	#		define LED_PIN 1
	#	endif

	#	ifndef HOST_USART
	#		define HOST_USART USART0
	#	endif

	#	ifndef HOST_TX_PORT
	#		define HOST_TX_PORT B
	#	endif

	#	ifndef HOST_TX_PIN
	#		define HOST_TX_PIN 2
	#	endif

	#	ifndef HOST_RX_PIN
	#		define HOST_RX_PIN 3
	#	endif

#elif defined( __AVR_ATmega_Mighty__ )
// For ATmega16, ATmega32, and the later x4 parts (up to the 1284P).


	#	ifndef HOST_USART
	#		define HOST_USART 0
	#	endif

	#	ifndef HOST_USART
	#		define HOST_USART 0
	#	endif

	#	ifndef UPDI_PORT
	#		define UPDI_PORT C
	#	endif

	#	ifndef UPDI_PIN
	#		define UPDI_PIN 7
	#	endif

	#	ifndef LED_PORT
	#		define LED_PORT B
	#	endif

	#	ifndef LED_PIN
	#		define LED_PIN 7
	#	endif


#elif defined (__AVR_ATmega_Mini__) || defined(ARDUINO_AVR_LARDU_328E)
	// For ATmega328 and 168 (P, PB) parts


	#	ifndef UPDI_PORT
	#		define UPDI_PORT D
	#	endif

	#	ifndef UPDI_PIN
	#		define UPDI_PIN 6
	#	endif

	#ifdef USE_SPIDEBUG

		#	ifndef LED_PORT
		#		define LED_PORT C
		#	endif

		#	ifndef LED_PIN
		#		define LED_PIN 5
		#	endif

	#else

		#	ifndef LED_PORT
		#		define LED_PORT B
		#	endif

		#	ifndef LED_PIN
		#		define LED_PIN 5
		#	endif

	#endif

#elif defined (__AVR_ATmega_Mega__)
// 2560 and that family, like the ones used on the Arduino Mega

	#	ifndef UPDI_PORT
	#		define UPDI_PORT D
	#	endif

	#	ifndef UPDI_PIN
	#		define UPDI_PIN 3
	#	endif

	#	ifndef LED_PORT
	#		define LED_PORT B
	#	endif

	#	ifndef LED_PIN
	#		define LED_PIN 7
	#	endif


#elif defined (__AVR_ATmega_Zero__ ) || defined( __AVR_DA__)
// 4808, 4809. and the rest of the megaAVR 0-series


	#	ifndef UPDI_PORT
	#		define UPDI_PORT B
	#	endif

	#	ifndef UPDI_PIN
	#		define UPDI_PIN 0
	#	endif

	#	ifndef LED_PORT
	#		define LED_PORT B
	#	endif

	#	ifndef LED_PIN
	#		define LED_PIN 1
	#	endif

	#	ifndef HOST_USART
	#		define HOST_USART USART0
	#	endif

	#	ifndef HOST_TX_PORT
	#		define HOST_TX_PORT A
	#	endif

	#	ifndef HOST_TX_PIN
	#		define HOST_TX_PIN 0
	#	endif

	#	ifndef HOST_RX_PIN
	#		define HOST_RX_PIN 1
	#	endif
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

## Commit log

2020-07-12 copy-paste LEDs in schematic
    [Page_1.sch, Page_2.sch, pcb.sch]
2020-07-12 link schematic leds to layout
    [Page_1.sch, Page_2.sch, pcb.sch]
2020-07-12 consider program over custom USB and remove 100 mil UPDI header
    [Page_1.sch, Page_2.sch, pcb.kicad_pcb]
2020-07-12 compontnets placedr
    [Page_1.sch, Page_2.sch, pcb.kicad_pcb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]
2020-07-13 pre-zone fill
    [Page_1.sch, pcb.kicad_pcb]
2020-07-14 candidate draft
    [pcb.kicad_pcb, pcb.sch]
2020-07-15 v1.0 as ordered
    [BOM.csv]
2020-07-18 case draft
    [BOM.xlsx, case_v1-0.FCStd]
2020-07-26 reinstall arduino ide where atmel studio can find it
2020-07-27 stencil ordered
    [BOM.xlsx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]
2020-07-27 thumb screws ordered
    [BOM.csv, BOM.xlsx]
2020-07-28 rainbow ripple implemented
    [case_v1-0.FCStd]
2020-07-29 generated stl and front panel pdf
    [case_v1-0.FCStd, case_v1-0.obj, case_v1-0.step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]
2020-07-29 fixed vent hole size being too large
    [case_v1-0.FCStd, case_v1-0.obj, case_v1-0.stl]
2020-07-31 added chamfer
    [case_v1-0.FCStd, case_v1-1.FCStd]
2020-07-31 added vent holes
    [case_v1-1.FCStd]
2020-07-31 removed face plate suports - no longer needed
    [case_v1-1.FCStd]
2020-07-31 finializing build 1-1
    [case_v1-1.FCStd, case_v1-1.obj, case_v1-1.stl]
2020-08-01 fix obj and stl export
    [case_v1-1.obj, case_v1-1.stl]
2020-08-03 lengthen mounting holes
    [case_v1-2.FCStd, case_v1-2.obj, case_v1-2.stl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]
